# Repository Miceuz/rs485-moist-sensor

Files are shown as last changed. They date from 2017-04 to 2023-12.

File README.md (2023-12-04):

# rs485 soil moisture sensor
Digital (RS485 - based) soil moisture and temperature sensor 



A version of [I2C soil moisture sensor](https://github.com/Miceuz/i2c-moisture-sensor) with several updates - antistatic protection, local voltage regulation and RS485 networking.

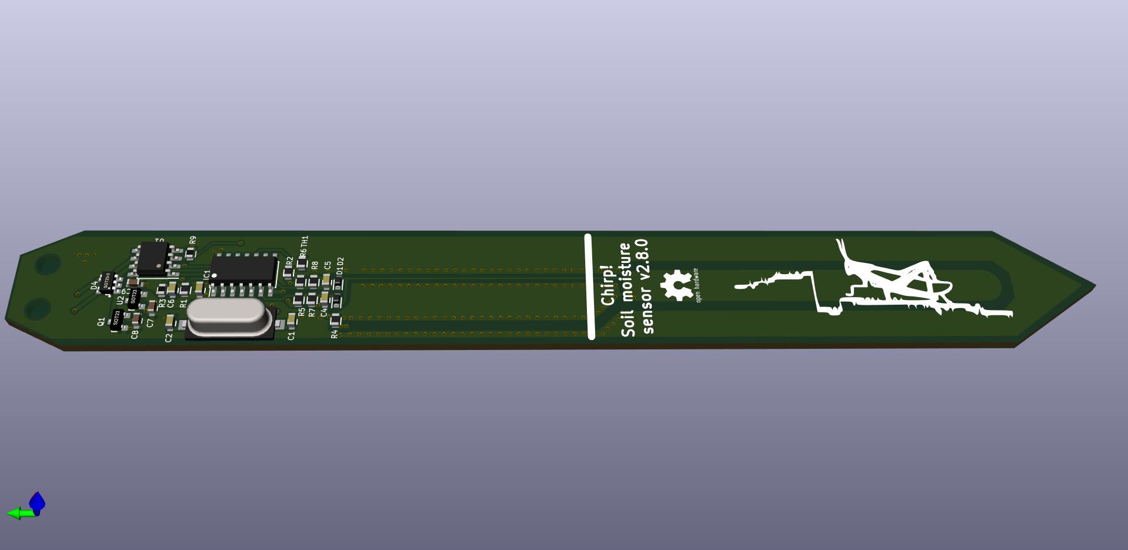
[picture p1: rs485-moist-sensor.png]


This is a contact-less capacitive soil moisture sensor, a continuation of my [I2C soil moisture sensor](https://github.com/Miceuz/i2c-moisture-sensor). This particular version of the sensor is suited for more professional installations where long cable runs is a requirement. It adds a local voltage regulator to mitigate the voltage drop and RS485 transceiver to accommodate long wires, also reverse polarity and an additional ESD protection level is added. 

This is the easiest and the most robust way to read soil moisture and temperature values into Raspberry Pi. I have written a [tutorial](https://github.com/Miceuz/rs485-moist-sensor/tree/master/tutorial) how to do it.

The main features:

 * Capacitive soil moisture sensing
 * Temperature sensing
 * Good stability with temperature
 * Good stability with power variation
 * Suitable for long cable runs
 * Uses industrial Modbus protocol

# Python library

A python library is available via pip. Type `pip install chirp_modbus` to install it. Check the [source code](https://github.com/Miceuz/rs485-moist-sensor/blob/master/utils/lib/chirp_modbus.py) for documentation. Usage example:
```python
from chirp_modbus import SoilMoistureSensor
s = SoilMoistureSensor(1, '/dev/ttyUSB5')
print(s.getTemperature())
print(s.getMoisture())
```

# Technical data

 * Supply voltage - 5V
 * Bus can be run on both 3V and 5V
 * Default serial settings: 19200, 8-bit frame, no parity, 2 stop bits
 * Default Modbus address: 1
 * Current consumption: Active: 9mA, Deep sleep: 11uA

## Principle of operation

Sensor makes periodic measurements (by default, once every 500ms), delays between measurements can be updated by writing to one of the Modbus registers. The results of the measurements are kept in specific Modbus registers and can be read by master any time unless the sensor is in deep sleep. 

Deep sleep is entered by writing a number of seconds to sleep into a special sleep register. The sensor will put the transceiver and all the periphery into the lowest possible power consumption mode and sleep for the specified amoutn of time. After the sleep the sensor will wake up, start taking measurements and be available on the bus till the next sleep command.

Serial communication parameters as baud rate, parity and address can be updated by writing to related registers. The sensor will reset and boot with the new parameters if any of those registers are written.

### Input (read only) registers

|Register number | Size (bytes) | Description |
|---|--- |---|
| 0 | 2 | Soil moisture. Unsigned |
| 1 | 2 | Temperature. Signed. In tenths of degrees Celsius. I.e. 220 means 22.0C |

### Holding (read/write) registers

|Register number | Size (bytes) | Valid values | Default value | Description |
|---|---|--- |---|---|
| 0 | 2 |  [1 - 247] | 1 | Modbus address |
| 1 | 2 |  [0 - 7] | 4 | Baud rate |
| 2 | 2 |  [0 - 2] | 0 | Parity **Note: most cheap ebay USB to RS485 dongles don't support parity properly!** |
| 3 | 2 |  [1 - 65535] | 500 | Measurement interval in milliseconds |
| 4 | 2 |  [1 - 65535] | 0 | Time to sleep in seconds. Write to this register to put the sensor to sleep. |

#### Supported baudrates

 Number | Baudrate
--------|---------
   0    |  1200
   1    |  2400
   2    |  4800
   3    |  9600
   4    |  19200
   5    |  38400
   6    |  57600
   7    |  115200

#### Supported parity settings

 Number | Parity
--------|---------
   0    |  None
   1    |  Even
   2    |  Odd

**Note: most of the cheap ebay USB to RS485 dongles and/or their drivers do not support parity setting properly! You will have to use a proper parity supporting adapter to unbrick the sensor if you set this to something that your dongle does not support!** Luckily Adruino with ATmega 16u2 can be used as USB to Serial adapter to solve this.

## How to interpret the readings

Moisture values are relative. Meaning, more moisture will give you higher reading, less moisture - lower reading. It's up to you to calibrate it to amount of water in the soil as readings will be different for different types of soils. 

Moisture is somewhat linear. I test all sensors before shipping and they give about 292 in free air. 

Temperature is measured by the thermistor on the body of the sensor. Calculated absolute measurement accuracy is better than 2%. The returned value is in tenths of degrees Celsius. I.e. value 252 would mean 25.2°C.

## Controller support

The sensor will work fine with any controller supporting serial communication provided you have an RS485 transceiver. There are a lot of Modbus libraries readily available for a variety of micro-processor families. Thea easiest way to try the sensor is to use one of the abundant and cheap USB to RS485 dongles and connect it to a Raspberry pi or even directly to your computer. 

I have written some basic test code in python that is available on [github](https://github.com/Miceuz/i2c-moisture-sensor/blob/master/README.md) page. 

## Waterproofing

The sensor comes coated with PRF202 - a moisture resistant varnish for electronics. It's ok for play around in a flower pot but not enough for outdoor use. **You must add an additional protection to the whole sensor after soldering cable to it!** Some suggestions on making the sensor more robust after attaching the cable:

 * Polyester or epoxy resin - this method is the most bullet proof as the resin is totally resistant to the water. On the par side, note that sensitivity of the sensor will decrease depending on how thick the layer you are going to apply. Also applying the resin in uniform manner presents some challenge.
 * PlastiDip - some of my customers have tried this method - easy to apply by spraying and not a lot of loss of sensitivity.
 * Rubber balloon - yes, just roll a long balloon over the sensor :)  

Be sure to coat the whole thing - the sensor part, the electronics and the cable connection itself so no bare copper or solder is accessible to the water.

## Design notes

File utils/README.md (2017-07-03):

# Python utils for RS485 soil moisture sensor

These utils demonstrate how to read and write registers to the sensor via Modbus. Utils use a  [minimalmodbus library](https://minimalmodbus.readthedocs.io/en/master/) refer to their documentation for installation instructions and more info.

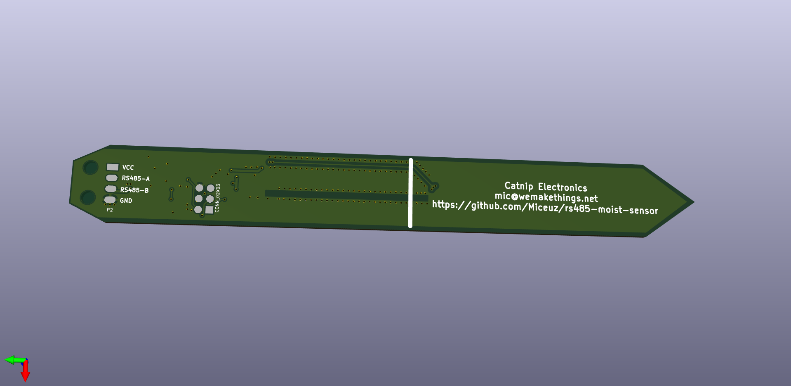
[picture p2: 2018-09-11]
rs485-moist-sensor-back.png

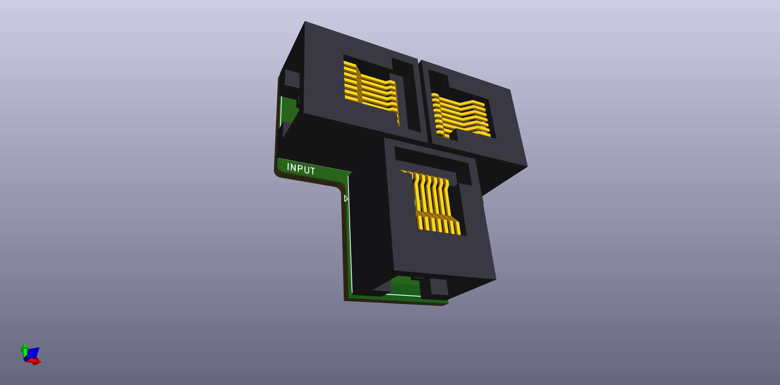
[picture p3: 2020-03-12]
interconnect/interconnect.png

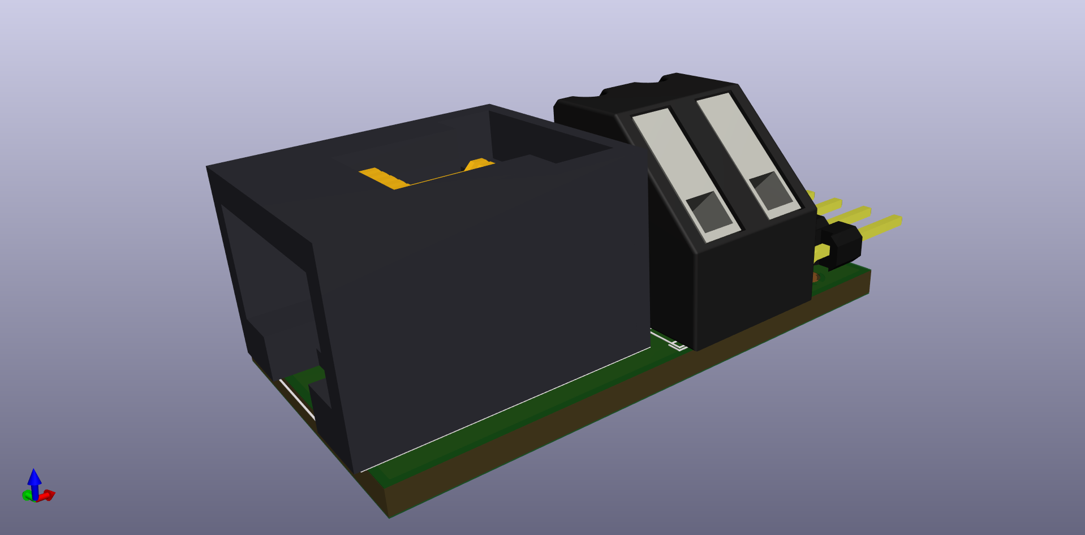
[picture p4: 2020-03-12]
adapter-por/adapter-por.png

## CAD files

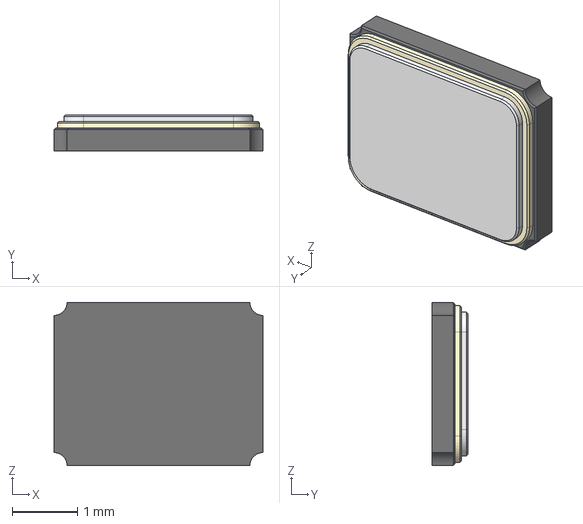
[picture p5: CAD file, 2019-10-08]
3d/CRY_SMD3225.STEP
3.20 x 0.55 x 2.50 mm

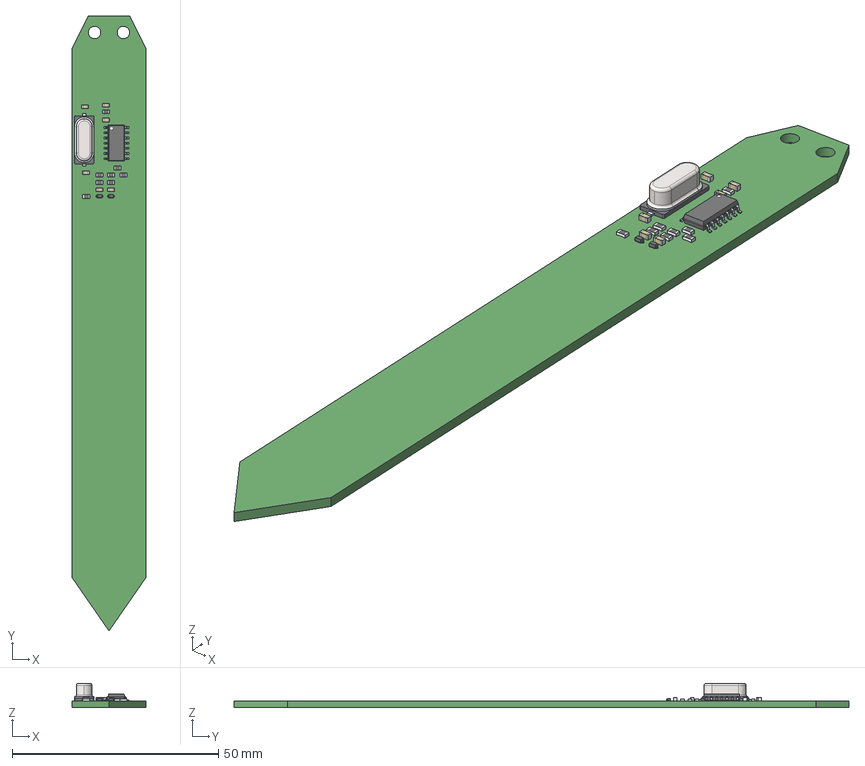
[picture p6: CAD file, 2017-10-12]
rs485-moist-sensor.stp
18.0 x 149.0 x 5.90 mm

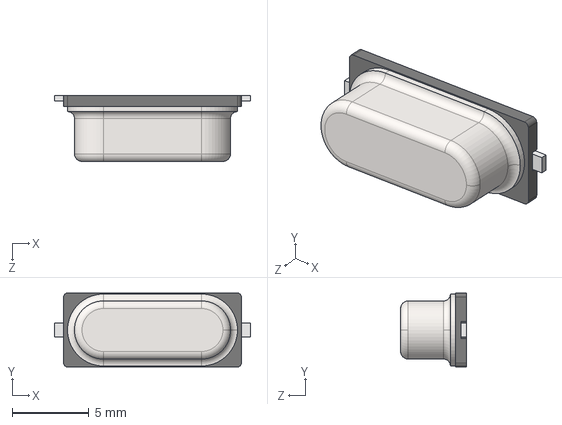
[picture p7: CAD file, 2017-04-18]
3d/User Library-Crystal HC49_US-SM.STEP
12.8 x 4.83 x 4.30 mm

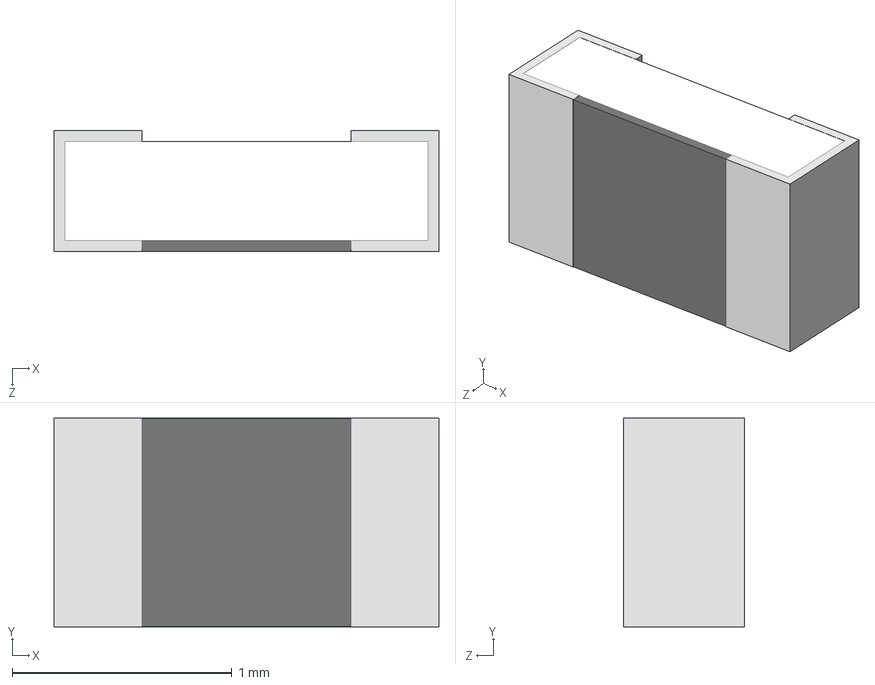
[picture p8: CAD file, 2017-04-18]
3d/User Library-RES_SMD-1.STEP
1.75 x 0.95 x 0.55 mm

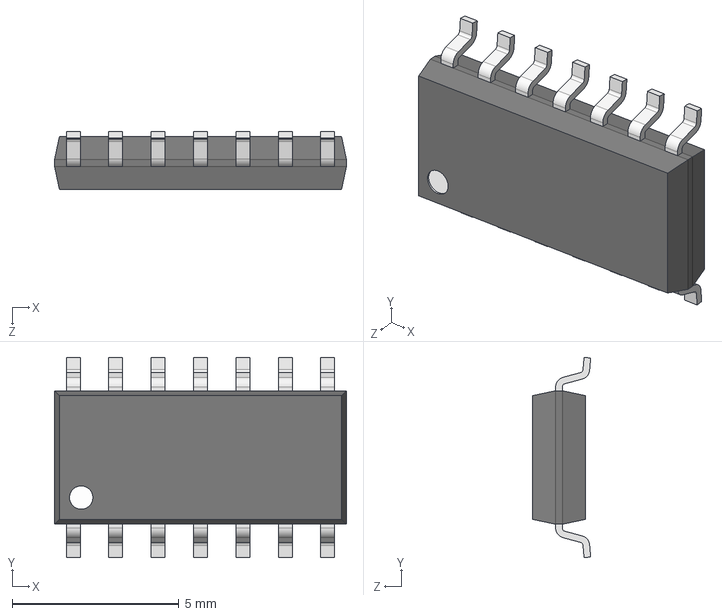
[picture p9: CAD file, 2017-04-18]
3d/User Library-SOIC-14.STEP
8.75 x 6.00 x 1.75 mm

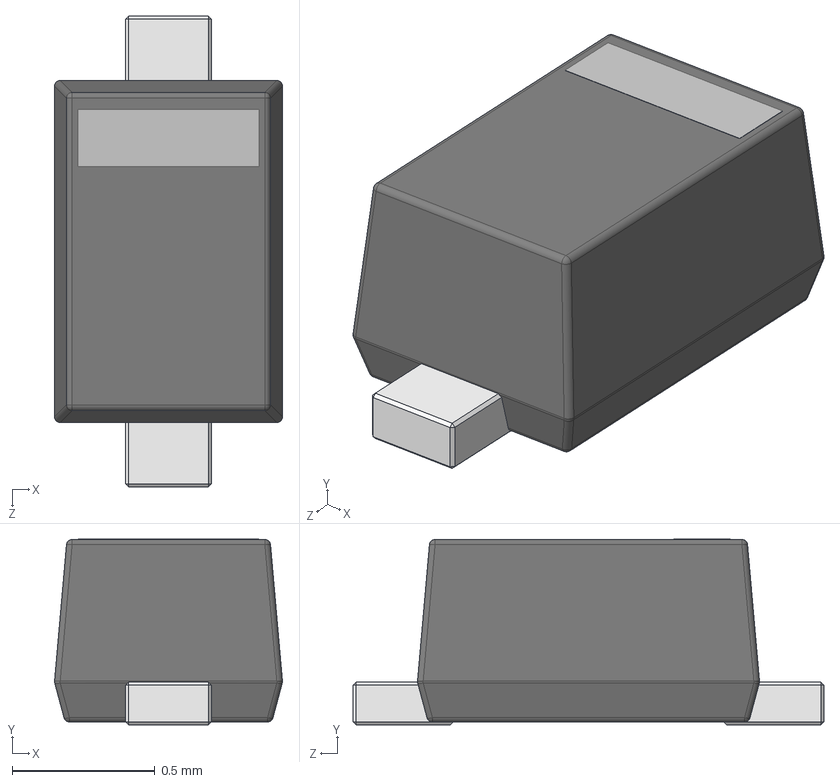
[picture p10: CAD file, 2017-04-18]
3d/User Library-SOD523-2.STEP
0.8 x 0.651 x 1.65 mm

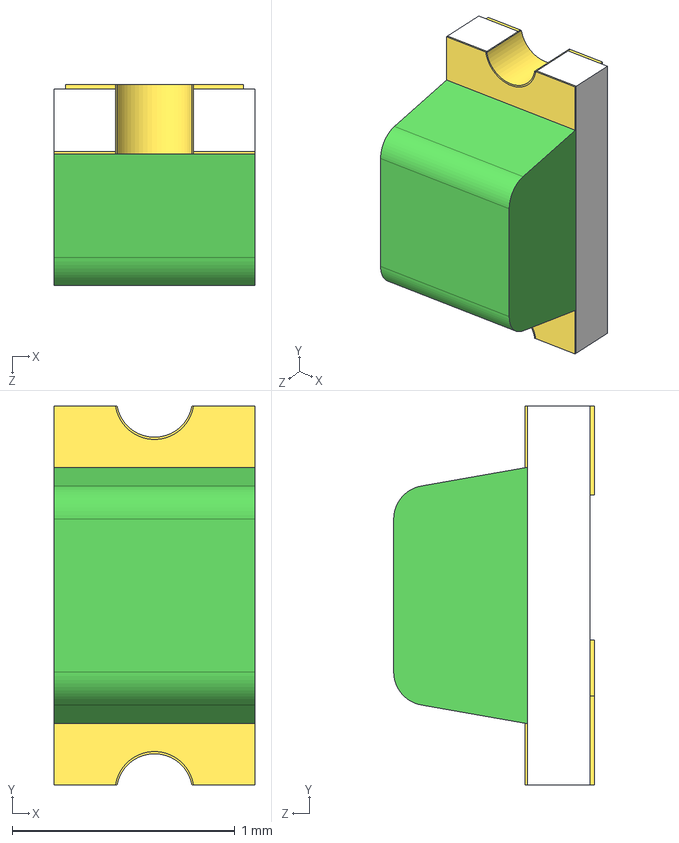
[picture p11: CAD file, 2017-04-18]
3d/User Library-LTST-C190GKT.STEP
0.9 x 1.70 x 0.9 mm
User Library-LTST-C190GKT_Pad005
User Library-LTST-C190GKT_Pad001
User Library-LTST-C190GKT_Pad004
User Library-LTST-C190GKT_Pad003
User Library-LTST-C190GKT_Lens
User Library-LTST-C190GKT_Pad

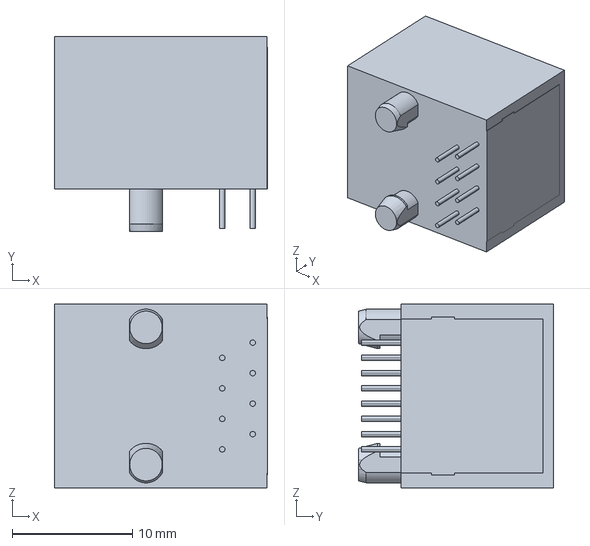
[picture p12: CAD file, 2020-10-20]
interconnect/54602-908LFc.stp
17.7 x 16.2 x 15.3 mm

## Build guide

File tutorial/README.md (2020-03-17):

# Talking to RS485 soil moisture sensor from Raspberry Pi

This tutorial will guide you how to get soil moisture and temperature readings from Chirp RS485 soil moisture sensor. These instructions are written with RaspberryPi in mind, but actually are valid for every python installation on Windows, Linux or OSX.

## What is RS485? Modbus?

RS485 is a standard defining the electrical characteristics for use in serial communications systems. It is a vary robust protocol allowing multiple devices on the same wire and long cable runs. Cable with at least 4 conductors is used to connect the sensors. You can hook up over 200 sensors on the same bus.

Modbus is a proven, industry standard protocol that goes over RS485 signalling layer. Communication happens between one master and multiple slaves. Each slave has to have a unique address. Master can read and write configuration and data registers of slave. Framing and data integrity is taken care of.

### USB - to - RS485 dongles

To talk to the sensor you will need a dongle that allows you computer to talk and listen on the RS485 network. Luckily RS485 is so popular that there is multitude of cheap dongles to choose from on ebay. Just enter "USB RS485" into the search terms and you will get a lot to choose from. Below are some examples that work fine. For convenience, choose one that has power pins +5V and GND broken out on the connector. Also you can hack the dongle by soldering wires to such points on the board.

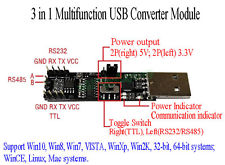
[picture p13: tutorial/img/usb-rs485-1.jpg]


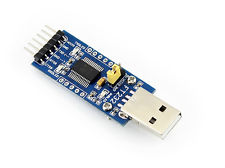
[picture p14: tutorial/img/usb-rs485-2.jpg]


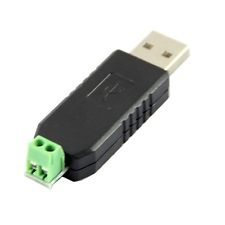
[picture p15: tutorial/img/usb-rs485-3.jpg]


### Wiring the connections

The sensor has 4 connections:

 * VCC - positive power supply. Apply 5V to this pin.
 * RS485-A - noninverting line of RS485 bus
 * RS485-B - inverting line of RS485
 * GND - negative power supply  

## Installing required software

Python environment and a chirp_modbus library is needed to communicate with the sensor.

To install all the needed Python infrastructure, type: 

```
sudo apt-get install python-pip
```

To install the chirp_modbus Python library type:

```
sudo pip install chirp_modbus
```

BAM! You are ready to go!

## Connecting to RS485 network

USB to RS485 dongle is really a simple device - it is just a simple USB to serial adapter plus a special RS485 transceiver chip. This means, that when you insert the dongle into your computer, a serial port will be created by your operating system. In Linux and OS X this happens automagically, but in Windows you will need to download the driver for the particular UST to serial chip used in your dongle. My example dongle uses CP2102.

Enter this command before inserting the dongle into Raspberry Pi: 
```
tail -f /var/log/syslog
```

Then insert the dongle. Something like this will appear:

```
Aug 30 20:37:01 raspberrypi kernel: [  839.161890] usb 1-1.2: new full-speed USB device number 4 using dwc_otg
Aug 30 20:37:01 raspberrypi kernel: [  839.297949] usb 1-1.2: New USB device found, idVendor=10c4, idProduct=ea60
Aug 30 20:37:01 raspberrypi kernel: [  839.297973] usb 1-1.2: New USB device strings: Mfr=1, Product=2, SerialNumber=3
Aug 30 20:37:01 raspberrypi kernel: [  839.297985] usb 1-1.2: Product: CP2102 USB to UART Bridge Controller
Aug 30 20:37:01 raspberrypi kernel: [  839.297995] usb 1-1.2: Manufacturer: Silicon Labs
Aug 30 20:37:01 raspberrypi kernel: [  839.298005] usb 1-1.2: SerialNumber: 0001
Aug 30 20:37:01 raspberrypi mtp-probe: checking bus 1, device 4: "/sys/devices/platform/soc/20980000.usb/usb1/1-1/1-1.2"
Aug 30 20:37:01 raspberrypi mtp-probe: bus: 1, device: 4 was not an MTP device
Aug 30 20:37:01 raspberrypi kernel: [  839.474676] usbcore: registered new interface driver usbserial
Aug 30 20:37:01 raspberrypi kernel: [  839.474812] usbcore: registered new interface driver usbserial_generic
Aug 30 20:37:01 raspberrypi kernel: [  839.474941] usbserial: USB Serial support registered for generic
Aug 30 20:37:01 raspberrypi kernel: [  839.489032] usbcore: registered new interface driver cp210x
Aug 30 20:37:01 raspberrypi kernel: [  839.489190] usbserial: USB Serial support registered for cp210x
Aug 30 20:37:01 raspberrypi kernel: [  839.489396] cp210x 1-1.2:1.0: cp210x converter detected
Aug 30 20:37:01 raspberrypi kernel: [  839.523446] usb 1-1.2: cp210x converter now attached to ttyUSB0
Aug 30 20:38:50 raspberrypi systemd[1]: Starting Cleanup of Temporary Directories...
Aug 30 20:38:51 raspberrypi systemd[1]: Started Cleanup of Temporary Directories.
```

This line is of importance here:

```
Aug 30 20:37:01 raspberrypi kernel: [  839.523446] usb 1-1.2: cp210x converter now attached to ttyUSB0
```

This means, the dongle now is accessible via /dev/ttyUSB0 serial port. Now it's time to write some code.

## Connecting to the sensor

From the command line start the Python interpreter:

```
$ python
```

You will be welcomed by Python interpreter:

```
$ python
Python 2.7.13 (default, Jan 19 2017, 14:48:08) 
[GCC 6.3.0 20170124] on linux2
Type "help", "copyright", "credits" or "license" for more information.
>>>
```

Type these commands:

```python
>>> import chirp_modbus
>>> sensor = chirp_modbus.SoilMoistureSensor(address=1, serialport='/dev/ttyUSB0')
>>> sensor.getMoisture()
201
```

BAM! You have just read moisture from the sensor! Try reading from the different register:

```python
>>> sensor.getTemperature()
20.0
```

Read the [source code](https://github.com/Miceuz/rs485-moist-sensor/blob/master/utils/lib/chirp_modbus.py) of the library for more.

## Addressing the sensors
All the sensors come with the same address preprogrammed to them, it's address **1**. Before using several sensors on the same bus, you have to assign unique address to each sensor. Luckily, this is just a matter of writing the address to the special Holding register:
```python
>>>sensor.setAddress(42)
```
This will set the address of the sensor to **42**. Sensor will reset and will listen on the new address immediately.

## Useful utilities
```python
#!/usr/bin/python

"""Waits for the sensor to appear on /dev/ttyUSB0, then reads moisture and temperature from it continuously"""

import chirp_modbus
from time import sleep

ADDRESS = 1

while True:
	try:
		sensor = chirp_modbus.SoilMoistureSensor(address=ADDRESS, serialport='/dev/ttyUSB0')
		# sensor.sensor.debug=True
		print(" Moisture=" + str(sensor.getMoisture()) +
			  " Temperature=" + str(sensor.getTemperature()))
		sleep(0.1)
	except (IOError, ValueError):
		print("Waiting...")
		sleep(0.3)
```

Address manipulation example:

```python
#!/usr/bin/python

"""Looks for sensor with ADDRESS1 and changes it's address to ADDRESS2 then changes it back to ADDRESS1""" 

import chirp_modbus
from time import sleep
ADDRESS1 = 1
ADDRESS2 = 2

sensor = chirp_modbus.SoilMoistureSensor(address=ADDRESS1, serialport='/dev/ttyUSB0')

print("writing new address: " + str(ADDRESS2))
sensor.setAddress(ADDRESS2)

sleep(0.2)
print("reading address from holding register: ")
print(sensor.getAddress())

print("writing new address: " + str(ADDRESS1))
sensor.setAddress(ADDRESS1)

sleep(0.2)

print("reading address from holding register: ")
print(sensor.getAddress())
```

Bus discovery example:
```python
import chirp_modbus

found = chirp_modbus.SoilMoistureSensor.scanBus(serialport='/dev/ttyUSB0', verbose=True, findOne=True, startAddress = 1, endAddress = 247)
```

### Bonus - pushing data to the Thingspeak

If you want to push your data to Thingspeak cloud, here is what you have to do.

Download thingspeak Python library:

```
$sudo pip install thingspeak
```
Set up your streak in [thingspeak.com](https://thingspeak.com)
Use this utility:

```python
#!/usr/bin/python
import chirp_modbus
from time import sleep, time
import thingspeak

channel = thingspeak.Channel(302723, api_key='YOUR API KEY', write_key='YOUR WRITE KEY')

SENSOR_PORT = '/dev/ttyUSB0'
ADDRESS = 1

sensor = chirp_modbus.SoilMoistureSensor(address=ADDRESS, serialport=SENSOR_PORT)

lastPostTimestamp = time()

moisture = 0
temperature = 0

while True:
	if time() - lastPostTimestamp > 3:
		try:
			moisture = sensor.getMoisture()
			temperature = sensor.getTemperature()
			try:
				channel.update({'field1':moisture, 'field2':temperature})
			except:
				print("#could not post")
			print(moisture, temperature)
		except(IOError, ValueError):
			print("#could not read sensor")
		
		lastPostTimestamp = time()

```

That's it folks! Please provide me feedback and send me pull requests!

### Bonus2 - pushing data to the local InfluxDB instance

```python
#!/usr/bin/python
import minimalmodbus
import serial
from time import sleep, time
from influxdb import InfluxDBClient
import RPi.GPIO as gpio

READING_INTERVAL_S = 3
SENSOR_PORT = '/dev/ttyUSB0'

ADDRESS = 1
minimalmodbus.CLOSE_PORT_AFTER_EACH_CALL = True
minimalmodbus.PARITY=serial.PARITY_NONE
minimalmodbus.STOPBITS = 2
minimalmodbus.BAUDRATE=19200
sensor = minimalmodbus.Instrument(SENSOR_PORT, slaveaddress=ADDRESS)

gpio.setmode(gpio.BCM)
gpio.setup(27, gpio.OUT)

lastPostTimestamp = time()

moisture = 0
temperature = 0

dbclient = InfluxDBClient(host='localhost', port=8086)
dbclient.switch_database('soil_sensors')

def formatForDb(moisture, temperature):
	points=[{
			"measurement":"data", 
            "tags":{"plant":"begonija"}, 
			"fields":{"temperature":temperature*1.0, "moisture":moisture*1.0}
			}]
	return points

def formatForDb(moisture, temperature, sensor_status):
	points=[{
			"measurement":"data", 
            "tags":{"plant":"begonija"}, 
			"fields":{"temperature":temperature*1.0, 
					  "moisture":moisture*1.0, 
					  "sensor_status":sensor_status}
			}]
	return points

def formatForDb(sensor_status):
	points=[{
			"measurement":"data", 
            "tags":{"plant":"begonija"}, 
			"fields":{"sensor_status":sensor_status}
			}]
	return points

def postToDb(points):
	try:
		dbclient.write_points(points)
		gpio.output(27, gpio.HIGH)
	except:
		print("#could not post")
		gpio.output(27, gpio.LOW)

try:
	while True:
		if time() - lastPostTimestamp > READING_INTERVAL_S:
			try:
				moisture = sensor.read_register(0, functioncode=4)
				temperature = sensor.read_register(1, functioncode=4, numberOfDecimals=1, signed=True)
				postToDb(formatForDb(moisture, temperature, "OK"))
			except(IOError, ValueError):
				postToDb(formatForDb("ERROR"))
				gpio.output(27, gpio.LOW)
				print("#could not read sensor")

			lastPostTimestamp = time()
except KeyboardInterrupt:
	print("Exiting...")
finally:
	GPIO.cleanup()

```

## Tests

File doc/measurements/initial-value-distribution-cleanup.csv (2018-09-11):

##Begins...
213 | 193
213 | 194
213 | 194
213 | 194
213 | 194
211 | 177
211 | 177
211 | 178
211 | 178
211 | 179
209 | 192
209 | 192
209 | 192
210 | 193
210 | 175
210 | 175
210 | 175
210 | 176
211 | 172
211 | 172
211 | 172
211 | 173
211 | 173
211 | 174
211 | 174
211 | 180
211 | 180
211 | 180
210 | 181
210 | 181
211 | 181
#Error: 226
210 | 183
210 | 183
210 | 183
210 | 183
210 | 183
210 | 185
210 | 185
211 | 174
211 | 174
211 | 174
211 | 174
210 | 175
210 | 175
210 | 175
212 | 178
212 | 179
212 | 179
211 | 180
212 | 176
212 | 176
212 | 176
212 | 177
212 | 177
212 | 178
212 | 178
212 | 178
211 | 173
211 | 173
211 | 174
211 | 174
211 | 175
211 | 175
210 | 176
210 | 178
210 | 178
210 | 179
210 | 179
210 | 179
210 | 179
210 | 179
210 | 181
210 | 181
210 | 181
#Error: 226
#Error: 226
210 | 189
210 | 190
210 | 190
210 | 191
210 | 191
210 | 191
209 | 191
209 | 191
210 | 191
210 | 174
209 | 174
209 | 174
210 | 174
210 | 174
210 | 174
209 | 175
#Error: 226
209 | 176
208 | 177
208 | 177
207 | 178
207 | 178
208 | 179
208 | 179
208 | 179
208 | 179
209 | 177
209 | 177
209 | 178
209 | 178
209 | 178
209 | 179
209 | 179
#Error: 226
#Error: 226
#Error: 226
209 | 183
209 | 183
209 | 183
208 | 183
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

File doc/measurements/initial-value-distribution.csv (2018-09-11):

##Begins...
213 | 193
213 | 194
213 | 194
213 | 194
213 | 194
211 | 177
211 | 177
211 | 178
211 | 178
211 | 179
209 | 192
209 | 192
209 | 192
210 | 193
210 | 175
210 | 175
210 | 175
210 | 176
211 | 172
211 | 172
211 | 172
211 | 173
211 | 173
211 | 174
211 | 174
211 | 180
211 | 180
211 | 180
210 | 181
210 | 181
211 | 181
#Error: 226
360 | 180
210 | 183
210 | 183
210 | 183
210 | 183
210 | 183
210 | 185
210 | 185
211 | 174
211 | 174
211 | 174
211 | 174
210 | 175
210 | 175
210 | 175
212 | 178
212 | 179
212 | 179
211 | 180
212 | 176
212 | 176
212 | 176
212 | 177
212 | 177
212 | 178
212 | 178
212 | 178
211 | 173
211 | 173
211 | 174
211 | 174
211 | 175
211 | 175
210 | 176
210 | 178
210 | 178
210 | 179
210 | 179
210 | 179
210 | 179
210 | 179
210 | 181
210 | 181
210 | 181
#Error: 226
#Error: 226
210 | 189
210 | 190
210 | 190
210 | 191
210 | 191
210 | 191
209 | 191
209 | 191
210 | 191
210 | 174
209 | 174
209 | 174
210 | 174
210 | 174
210 | 174
209 | 175
#Error: 226
209 | 176
208 | 177
208 | 177
207 | 178
207 | 178
208 | 179
208 | 179
208 | 179
208 | 179
209 | 177
209 | 177
209 | 178
209 | 178
209 | 178
209 | 179
209 | 179
#Error: 226
#Error: 226
#Error: 226
209 | 183
209 | 183
209 | 183
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

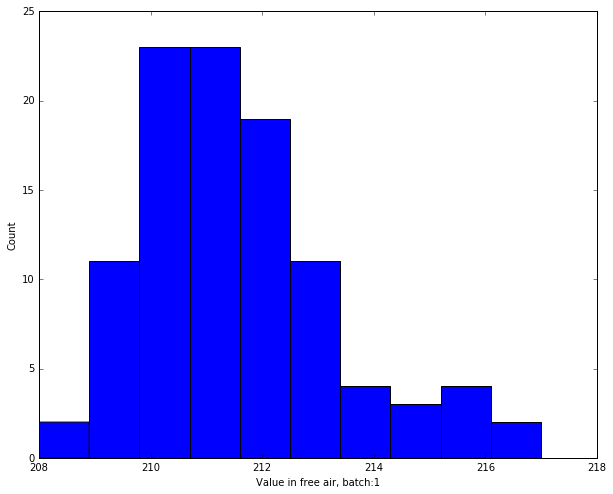
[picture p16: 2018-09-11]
doc/measurements/initial-value-batch1.png

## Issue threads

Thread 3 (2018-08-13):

measurement interval lost after sensor reboot

impellerturn, 2018-08-13:
Hi,
i somehow have an issue with the measurement interval.
it seems that its  not correctly stored in EEPRom and initialized to a very high value after power off->on.

here is what i did:
>>> pi@raspberrypi:~/Documents/WateringSystem $ python3
>>> Python 3.5.3 (default, Jan 19 2017, 14:11:04)
>>> [GCC 6.3.0 20170124] on linux
>>> Type "help", "copyright", "credits" or "license" for more information.
>>> from chirp_modbus import SoilMoistureSensor
>>> sensor = SoilMoistureSensor(10, "/dev/ttyUSB0")
>>> sensor.getMeasurementInterval()
65524
>>> sensor.setMeasurementInterval(123)
>>> sensor.getMeasurementInterval()
123

**Power off sensor, power back on**

>>> sensor.getMeasurementInterval()
65524

**Reinitialize python object, turns out this was not the issue**

>>> sensor = SoilMoistureSensor(10, "/dev/ttyUSB0")
>>> sensor.getMeasurementInterval()
65403
>>> sensor.getMeasurementInterval()
65403
>>> sensor.getMeasurementInterval()
65403
>>> sensor.getMeasurementInterval()
65403
**set another interval**
>>> sensor.setMeasurementInterval(123)
>>> sensor.getMeasurementInterval()
123
>>> sensor.getMeasurementInterval()
123
>>> sensor.getMeasurementInterval()
123
>>> sensor.getMeasurementInterval()
123
>>> sensor.getMeasurementInterval()
123
>>> sensor.getMeasurementInterval()
123
>>> sensor.getTemperature()
26.4
>>> sensor.getTemperature()
26.4
>>> sensor.getTemperature()
26.4
>>> sensor.getMoisture()
229

** here the test, if the data is updated fast, yes it is**
>>> sensor.getMoisture()
416
>>> sensor.getMoisture()
227
>>> sensor.getMoisture()
227
>>> sensor.getMeasurementInterval()
123
>>> sensor.setMeasurementInterval(500)
>>> sensor.getMeasurementInterval()
500
>>> sensor.getMeasurementInterval()
500
>>> sensor.getMeasurementInterval()
500
>>> sensor.getMeasurementInterval()
500

** power off sensor, power back on**

>>> sensor.getMeasurementInterval()
65524
>>> sensor.getMeasurementInterval()
65524

cheeeeee, 2019-02-10:
I realize this is old but you are correct. There was an error with how the measurement interval was stored to eeprom.  I THINK I have this fixed but i'm still going through stuff and I'm not sure this project is even supported any more.

Miceuz, 2019-02-11:
Hi, the project is still very much supported, thanks for your contributions. Would you mind forking it from mine and adding you changes to the forked branch so I could import them to my repository?

Thank you very much for the contribution! I am a bit busy right now, but I will come back to your questions in couple days.

cheeeeee, 2019-02-11:
Oh yeah it's already forked and under [https://github.com/cheeeeee/RS485_AtmelDebug/tree/master/src](https://github.com/cheeeeee/RS485_AtmelDebug/tree/master/src). The issue here was a mismatch between the initial array declaration being u16 and the eeprom stores being u8.  On my branch everything is u16 and all values are written to eeprom as u16 and loaded as u16.  Also the loadconfig() function wasn't fully finished and now is in working order.  I'm still working on stuff so I don't know if I really have a stable build yet or not so you have time.

impellerturn, 2019-02-12:
Hi,
good to hear from you.
I have 3 of these sensors and are also still interested in bugfixes.
Best regards

cheeeeee, 2019-02-17:
Added some possibly stable .elf and .hex files at [https://github.com/cheeeeee/RS485_AtmelDebug/tree/master/src/Release](https://github.com/cheeeeee/RS485_AtmelDebug/tree/master/src/Release)
If anyone is brave enough to try and flash their sensors.  Hopefully I can get a programming setup to test these patches out this week.

impellerturn, 2019-02-24:
Hi,
mine are buried and also sealed, so "quick testing" is not possible for me :(
Sorry, best regards

Miceuz, 2019-03-03:
I think this bug might be a combination of the bug in the library as incorrect register number was specified for measurement interval AND MAYBE eeprom saving issue. @cheeeeee is correct - I should be saving 16bit values, not 8 bit. Even though I don't use them all. Will work on that

cheeeeee, 2019-03-18:
Yeah when I was going through it you could do a mix of 8 bit and 16 bit ints but honestly it's just way easier to make everything 16 bit even if it's a little inefficient.  If there's anything you want me to look at more in depth just let me know i'll be happy to do it.

Gagi2k, 2020-04-20:
I guess my sensors have the same bug. I have 20 sealed sensors, most of them buried, but i also have some replacements at my desk. Do you think these saving issues can also affect other areas (not just the measurement interval) which could make the device stop working completely and not answer anymore ?
All my replacement sensors (which were not used once, just used for a basic check when i got them) are all not answering anymore. I extended your python library to scan all baudrate/parity combinations, but no response. Any help on what i can do to debug the problem or fix/reflash is very welcome *g*

impellerturn, 2020-04-21:
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

I had a similar issue with the sensors stopping reponding. But i did not associate it with the storing problem.
I was reading the values for temp and moisture every second and after a while (random, usually something between 2 and 24 hours) none of the sensors attached to the bus was reponding.
Only thing that helped was cutting the power supply and giving them a hard-restart.
At that point i´ve discarded the idea of measuring moisture and went back to basic time sheduling of my irrigation system.

chris-b-tanner, 2021-04-18:
Is this issue still open? I have similar behaviour across multiple sensors; after powering down and up again the reading interval requires checking and resetting regularly to ensure correct readings. I also have the odd occurrence when the slave ID is reset to 1, which causes much more trouble as when there are multiple devices on the bus, it's not fixable by the master.

Miceuz, 2021-04-19:
I have pinpointed that to a power sequencing issue. I don't know yet what, but something causes the sensor to corrupt eeprom when power is rising/falling too slow. I.e. this should happen while turning of/on the whole string of sensors.

Increasing BOD value seemed to help, so I did that for my current batch of sensors.

But also I have a hardware solution that powers sensors and disconnects both power and modbus lines when voltage is too low. If anyone wants, I can send that as a bandaid fix for this problem, contact me directly plz.

Also just disconnecting cable instead of allowing slow switch off of the power supply is an option if you have it on a connector.

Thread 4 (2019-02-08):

A few questions about the ATTiny441 programming

cheeeeee, 2019-02-08:
If you get a chance I had a few questions about some of the modbus programming in modbus.c and main.c
# Possible problems:
### In modbus.c --

#### Function Problems:
`bool validateFrame()`
Line 169 -- `uint8_t requestedAdr = getRequestedAddress();`  `requestedAdr` is never used in this function.
`ISR(UART_RECEIVE_INTERRUPT)`
Line 210 -- `uint8_t parityError = (UCSR0C & _BV(UPM01) && (UCSR0A & _BV(UPE0)));`never used in this function.

### In main.c --
#### General Problems:

`F_CPU`
This is defined by default in delay.h as 1MHz and defines the clock cycle. This is probably undefined behavior.

Line 193 -- `ISR(WDT_vect)`
WDT_vect isn't supported on the ATTiny44 according to [https://www.nongnu.org/avr-libc/user-manual/group__avr__interrupts.html](https://www.nongnu.org/avr-libc/user-manual/group__avr__interrupts.html). This is supported if you use Atmel's special header file iotn441.h
This might explain the comment saying you were having problems with it.

#### Function Problems:
`modbusGet(void)`
Line 123 -- `if (modbusIsFrameAvailable())` when true this enters a switch case statement with a default behavior, however there is no error returned if `modbusIsFrameAvailable()` returns false.
Between line 160 and 161 a modbus error should probably be returned to handle a false boolean.

`sleep()`
Line 234 -- might not be a problem but I think you have an unneeded compare.
on line 228 you have `secondsToSleep = holdingRegisters.asStruct.sleepTimes;`
since you've assigned these values to be equal when you do the compare on line 235 `while((sleepTimes > 0) || (secondsToSleep > 0))` I'm pretty sure you're just checking two numbers that are always the same in this particular function.  You can probably use if and just check one.

Line 297 -- incorrect primitive for main
```
void main (void) {
}
```
should be
```
int main (void) {
}
```

Lines 318 and 324

Incorrect primitives for temp.  Needs to be signed to allowed for negative values. Initial declaration is correct but is incorrect in function call.

`(uint16_t*) &(inputRegisters.asStruct.temperature));`
should be
`(int16_t*) &(inputRegisters.asStruct.temperature));`

# Questions!
1. What do you think the F_CPU cycle should be set to? I'm assuming 16MHz to match the crystal but it might be 8 MHz to match the ATTiny441 default clock.
2.  Currently if I write to a value to the sleep register it won't wake up until that counter expires or the sensor is power cycled.  Is this intentional or a bug? It seems like requesting a read operation should wake the sensor.  I think with the  iotn441.h header fix this could be easily done with a watchdog interrupt.

You can find everything I've done to these files at [https://github.com/cheeeeee/RS485_AtmelDebug](https://github.com/cheeeeee/RS485_AtmelDebug) Including some additional API documentation in main.c if you haven't looked at this in a while and need a refresher.

cheeeeee, 2019-02-15:
I answered question 1 for myself.  Turns out iT was defined in the original makefile as 16MHz and my compiler was giving me an undefined error because Atmel studio was managing my makefile for me.

Miceuz, 2019-03-03:
Hi, thanks for your feedback.

F_CPU is defined in Makefile

This is attiny441, not attiny44, avr-libc was lagging behind a bit.

modbusGet is polled from the mail loop, it does not result in error if there is no modbus frame to process, it simply did not come yet.

You are right about double nested sleep loop - something is fishy there. But you are mixind two things sleepTimeS means "sleep time in seconds" while sleepTimes means how many times sleep was performed.

Also you are right regarding the pointer type for the temperature -- will fix that.

Tha fact that sensor is not accessible during sleep is by design as I want to save the power by putting the rs485 transceiver to shutdown also. I do that by disabling both reader and driver.

Thanks again for you contribution!

cheeeeee, 2019-03-05:
Yep. I was a little confused since the astruct and variable had the same name. I clarified that in my pull request if you don't mind it.  Thanks for getting back to me.  Hopefully I can flash the firmware on my sensor with my updated code to make sure it's gonna work when I get a chance to.

Closed 2019-03-05.

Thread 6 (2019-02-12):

RS485 Bus stops after a few days

impellerturn, 2019-02-12:
Hello,
i´ve encountered, that my sensors are not working after a few days of operation.
### Setup
- 3 Sensors
- overall bus length 25m
- Termination: VCC <-> 390Ohms <-> RS485-line-A <-> 220Ohms <-> RS485-line-B <-> 390Ohms <-> Ground
- Termination is at my USB to RS485 Transceiver

### Measurement
- set measuerement interval to 500ms
- do 100 measuerements, read the data once per second then calculate mean on the data
- then do the next 100 measuerements

### Result
- This runs fine for about 2 days but occasionally stops.
- Tested with the USBtoRS485 converter sold by @Miceuz and also with a different one. Same results.
- Only pwer cycling the whole bus helps.

Has anyone else had similar issues? Maybe @[cheeeeee](/cheeeeee)?

Any help appreaciated, thanks and best regards

cheeeeee, 2019-02-12:
My initial thought might be the watchdog timer on it. It looks like the WDTCSR is still in the works honestly. I don't even have my sensors in production yet since I'm still going through the firmware.  I'll see about looking into improving the watchdog on it and submitting a pull request since Albertas seems pretty busy.  If you're not familiar, a watchdog timer basically monitors for a loop condition and if a timeout is reached it resets the device automatically.  To keep that from happening you have to keep on feeding the watchdog timeout conditions.  Is there a delay between when you do batches of measurements? Can you try a lower number of reads and report back? Like say 50 reads and average and see if it dies in 2 days or something like 4 days?

impellerturn, 2019-02-14:
Hi,
i´ve tried bringing my system up yesterday but something with MQTT did not work out. Will look for it on the weekend.
Here is my code to use the sensors. It requires the mosquitto python module along with some standard python libs. Dont have a public repo yet.

[soilmoisturereader.zip](https://github.com/Miceuz/rs485-moist-sensor/files/2863887/soilmoisturereader.zip)

Best regards

cheeeeee, 2019-02-14:
Okay just fair warning I haven't used python before but everything that I see on your controllers looks good to me.  Most errors are handled and you should be getting exceptions reported if there is an error in the controller querying the modbus devices.  Try using a lower query rate like I suggested before and see if that changes anything.  If it does that might indicate a limit or bug with MQTT. There was a POSSIBLE error with a write protected register in attint441 programming when sleep was called and a reset might not be initiated and an infinite loop would occur. I included that fix with with other request but I have all of 4 weeks of experience with cpp and about 3 weeks of experience writing c so I'm mostly going off of datasheets and research here.  Albertas will really need to check it all and program one and see what happens.  If what I have doesn't fix it we might have to approach it from a different angle. Just wait and see at this point. Hopefully this works.

Miceuz, 2019-03-03:
@cheeeeee reset() in not called from sleep().

Sensor is configured in Safety Level 1.

> In this mode, the Watchdog Timer is initially disabled, but can be enabled by writing the WDE bit to one without any restriction. A timed sequence is needed when disabling an enabled Watchdog Timer.

@impellerturn are you putting sensors to sleep?

impellerturn, 2019-03-03:
Hi,
no i do not bring the sensors to sleep.

Miceuz, 2021-04-18:
Sorry, I have totally forgotten this.

My suspicion lies with the powering. How many sensors are powered from a single usb dongle? I wouldn't use USB dongle as a permanent power solution. It can supply only one - two sensors.

impellerturn, 2021-04-19:
There were 3 sensors powered by the usb dongle.
In the first post i've listed a detailed description of the system setup.

As of today i do not have the setup any more.

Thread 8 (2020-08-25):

Compiling Toolchain

yuregir, 2020-08-25:
Hello,

I am having some problems with compiling the code.
I am using Mac and brew to setup the toolchain.
I am not able to compile using 4.9.2 compiler which isnt have attiny definitions, the minimum version I can use is 5.3 compiler, when I am using 5.3 compiler code compiles succesfully but, rs485 tranciever enable pin stuck at transmit mode so sensor is not able to receive any modbus data.
There is something I am missing but coulnt find root of the issue
I was wondering anyone can help me on toolchain setup. Or is there any precompiled binary ?

Regards

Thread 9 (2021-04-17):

Sensor readings incorrect when temp below zero

chris-b-tanner, 2021-04-17:
I have a range of sensors based on the schematic and layout of this project, which work brilliantly - apart from when the temperature goes negative. I get a reading from the registers of 65515, or close to (it's not exactly the same each read). Does anyone get this from the original RS485 sensors which are shipped via Tindie?

The firmware is from this project, up to date.

cheeeeee, 2021-04-17:
It's most likely going to be an integer overflow error where an unsigned value should be signed. Since it's used for watering I actually haven't bothered testing values below freezing.

chris-b-tanner, 2021-04-17:
@cheeeeee we use our sensors for controlling heaters as well as pumping water, and also to prevent pumping cycles when the water might be frozen. I suspect it's in the firmware too but my knowledge of the code isn't up to this level of debug. Is there anything in the firmware that looks suspicious to you? The fact that it's exactly at the zero crossover suggests that is is a signed/unsigned problem. There's no problem with the i2c version of this sensor which reads nicely below zero.

Miceuz, 2021-04-17:
I am not at my pc now, cant investigate, but i guess this is just receiving library thing. If you subtract 65535 you will get a correct negative number

On April 17, 2021 11:03:49 PM GMT+03:00, Chris Tanner ***@***.***> wrote:
***@***.*** we use our sensors for controlling heaters as well as pumping
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

--
Sent from my Android device with K-9 Mail. Please excuse my brevity.

cheeeeee, 2021-04-17:
It'll be lines 27-35 of main.c then most likely if the ic2 read correctly below zero where int16 is mismatched from uint16.  The array declaration probably has type conversion of the contents.

chris-b-tanner, 2021-04-18:
@cheeeeee if you have time to fix on your fork, I'm happy to run some hardware tests below zero. I believe your fork also has a fix for issue with reading interval resetting which isn't yet in this repo?

Miceuz, 2021-04-18:
Guys, I don't get what are you talking about - both in main.c and in measurement.c (where actual measurement is performed) and in thermistor code - everywhere I see signed type used.

What are you using to read the sensor? If it's python library provided by me, then update it, I have fixed this in the library more than a year ago. And I am seeing negative temperatures - I have done environmental chamber tests a year ago.

Also note that at modbus master side you have to decide (or inform your modbus driver to do so) if you will interpret the reading as unsigned or a signed number. Have a look, minimalmodbus has a separete argument to specify that:

https://github.com/Miceuz/rs485-moist-sensor/blob/6bc4947f385b5dd4cc75266e2c948ae950f28cb6/utils/lib/chirp_modbus.py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

cheeeeee, 2021-04-18:
Oh no I'm referring to main.c not the .py files

`volatile union{
            uint16_t asArray[3];
            struct {
                uint16_t moisture;
                int16_t temperature;
                uint16_t fwVersion;
            } asStruct;
        } inputRegisters;`

This would be the firmware for the attiny441. Best guess is that since you have an array that's declared as unsigned the compiler may say that all things inside the array need to be unsigned and convert them. Maybe. I've sort of abandoned working with the modbus as of now since the cabling is really to expensive to deploy at scale so I just haven't looked at these sensors as of late.

https://github.com/Miceuz/rs485-moist-sensor/blob/master/src/main.c

Miceuz, 2021-04-18:
Ok, got it. This really does nothing to the negative value. Both `-12` and `65524` have the same binary representation:
`0b1111111111110100`

As I have said, the problem is in decoding at the masters side. @chris-b-tanner can you give more details on what do you use to read sensors?

BTW `65515` is `-21` really, were you testing sensors in a freezer?

cheeeeee, 2021-04-18:
Correct it would effect the sign bit on the binary so no matter what a positive would be returned. It would just drop the sign bit assuming that it wouldn't be used.

Miceuz, 2021-04-18:
No, it wouldn't affect the sign bit as unsigned numbers use this bit to store information. You can store 0-65535 or -32767-32768 in two bytes.

chris-b-tanner, 2021-04-18:
> As I have said, the problem is in decoding at the masters side. @chris-b-tanner can you give more details on what do you use to read sensors?
> BTW `65515` is `-21` really, were you testing sensors in a freezer?

Yes, I've been testing in a freezer. I've been using a ModbusMaster package with an ESP32/Arduino IDE to read the value, and can easily subtract 65535 when appropriate. My minsuderstanding here - thank you for input! Great pieces of kit.

Miceuz, 2021-04-19:
@chris-b-tanner you don't have to do any arithmetics, you can simply cast the result to signed type:

```c
temperature = (int16_t) node.getResponseBuffer(j);
```

Closed 2021-04-18.

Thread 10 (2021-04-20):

Possible to use 1-wire?

bvduijn, 2021-04-20:
Hi Albertas,

I see you also have a version of the moisture sensor using RS-485. I was wondering if it is possible to use 1-wire, more specific. a DS2438Z+ ADC

My idea is to use the 1-wire bus to power the chirps as well. Perhaps not using the chirp function at all but do it centrally and use the moisture sensor purely as a sensor

Hope to hear your thoughts on this.

KR
Bert

Miceuz, 2021-04-23:
While this is an interesting idea, but I am not sure if if this is the right part. I would look into implementing one wire protocol directly on attiny.
DS2438Z is an ADC, but we also need a square wave to excite the sensor.

Closed 2021-04-23.

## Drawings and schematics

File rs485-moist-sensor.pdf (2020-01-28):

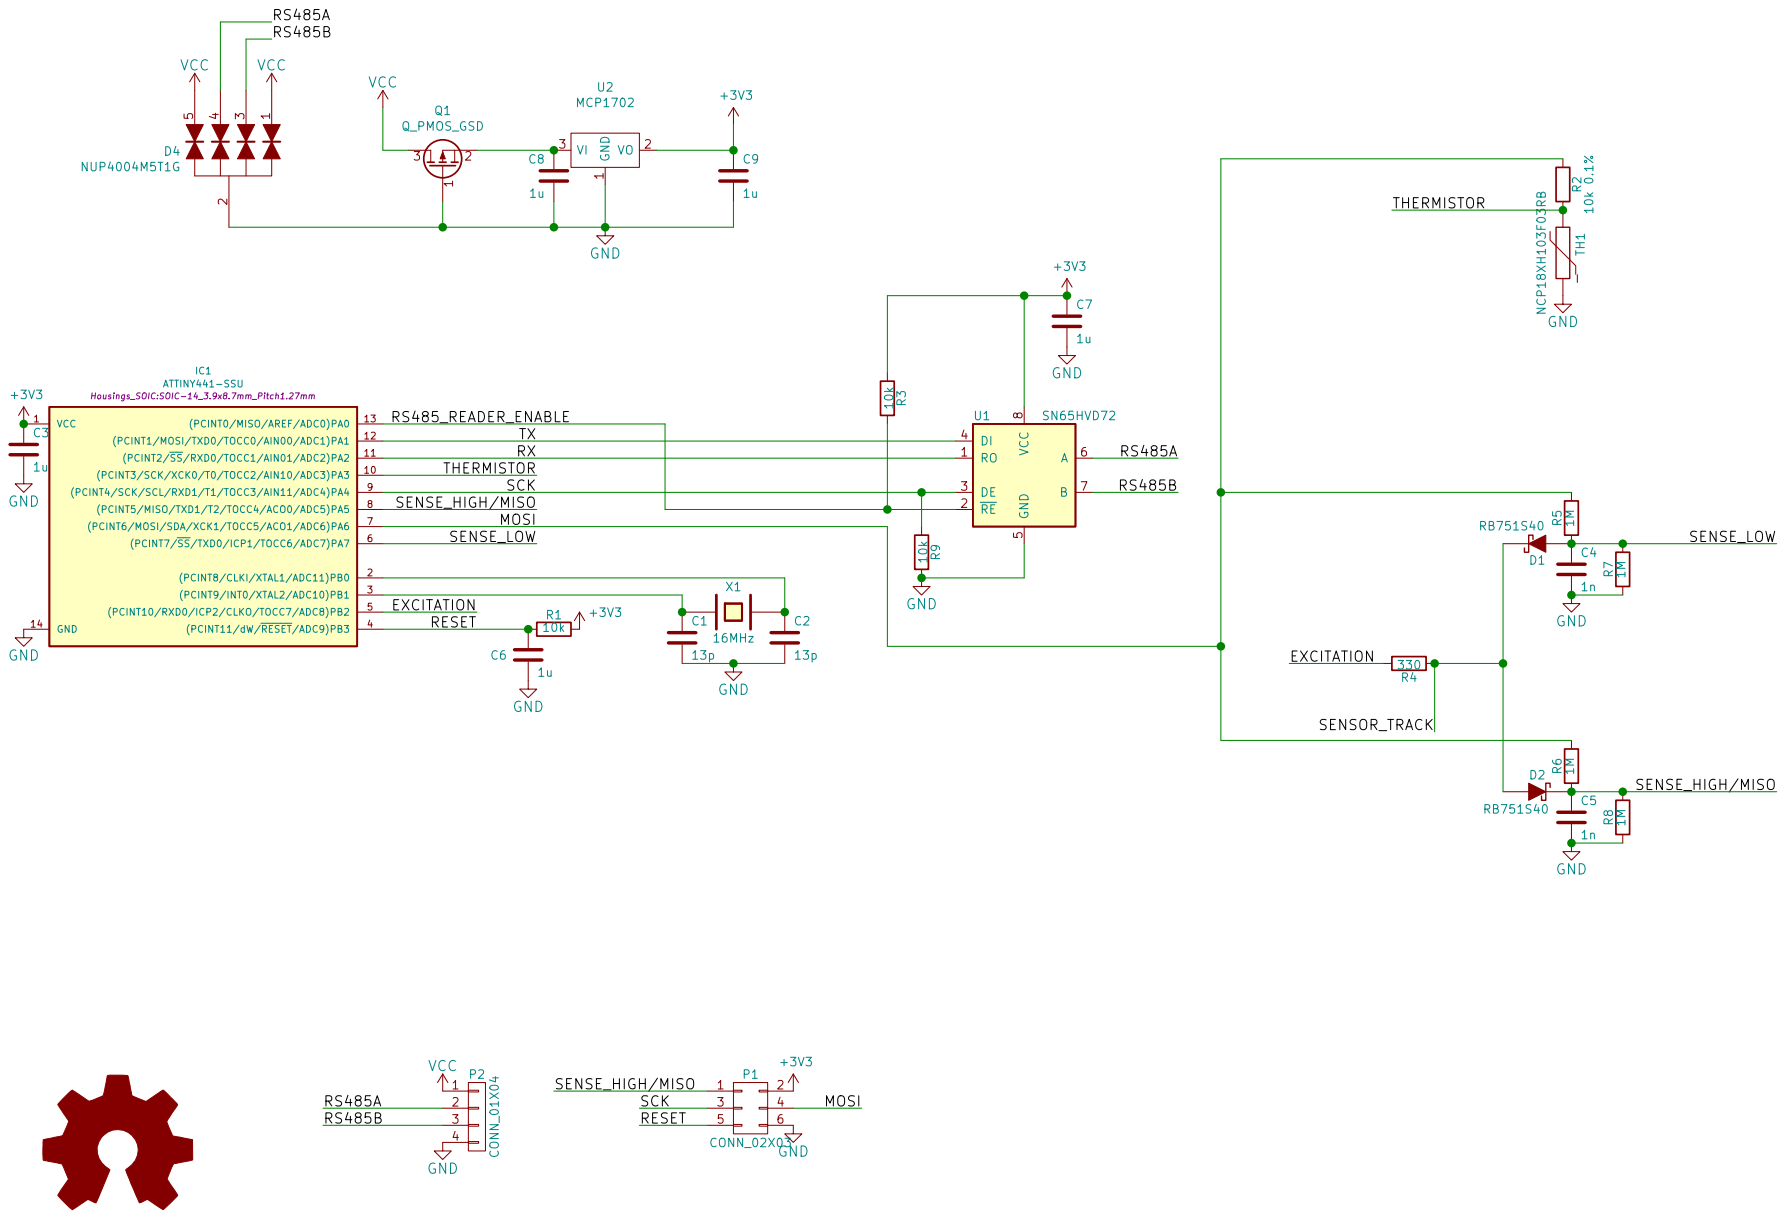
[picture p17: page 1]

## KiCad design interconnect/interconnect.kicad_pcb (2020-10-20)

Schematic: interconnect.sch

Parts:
C1: C; C_0603_1608Metric_Pad1.05x0.95mm_HandSolder
J1, J2, J3: RJ45; RJ45_Amphenol_54602-x08_Horizontal

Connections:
GND: C1.2, J1.3, J1.5, J1.7, J2.3, J2.5, J3.3, J3.5, J3.7
unnamed: J1.1, J2.1
unnamed: J1.2, J2.2
unnamed: J2.7, J3.1
unnamed: J2.8, J3.2
VCC: C1.1, J1.4, J1.6, J1.8, J2.4, J2.6, J3.4, J3.6, J3.8

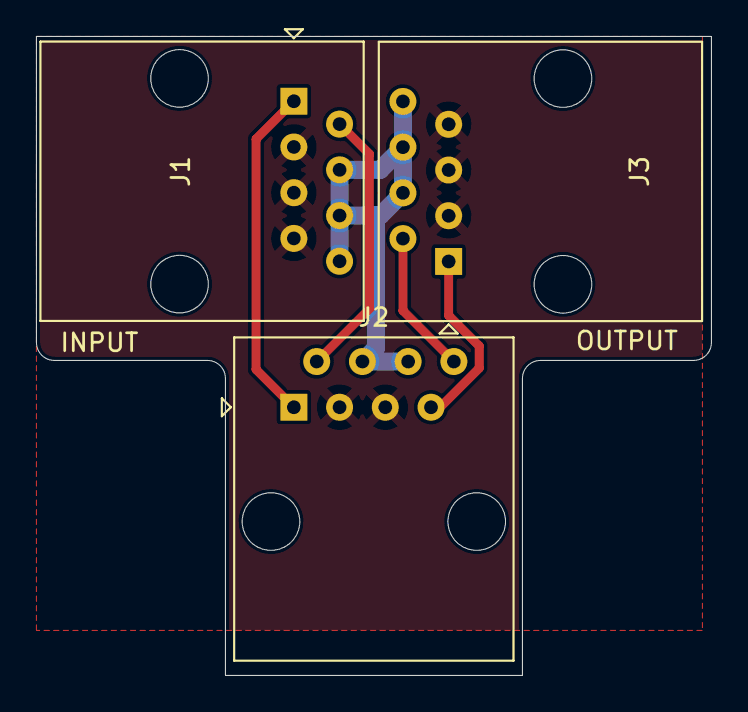
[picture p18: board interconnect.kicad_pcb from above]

Board: 2 copper layers, 37.5 x 35.5 mm, 4 parts (1 on the bottom side), 6 nets.

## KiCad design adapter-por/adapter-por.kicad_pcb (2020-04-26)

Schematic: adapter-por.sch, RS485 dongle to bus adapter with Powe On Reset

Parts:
C1, C2, C3, C4, C5: C; C_0603_1608Metric
D1: LED; LED_0603_1608Metric
J1: Conn_01x04_Male; Pin_Header_Angled_1x04_Pitch2.54mm
J2: RJ45; RJ45_Amphenol_54602-x08_Horizontal
J3: Conn_01x02_Male; TerminalBlock_RND_205-00287_Pitch5.08mm
R1, R2, R3, R4, R5, R7: R; R_0603_1608Metric
R8: 120; R_0603_1608Metric
U1: MCP100; SOT-23
U2: MCP2505; SO-8_3.9x4.9mm_P1.27mm
U3, U4: SN74LVC1G3157; SOT-23-6

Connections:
/A: J1.2, U4.1 (B2)
/A_OUT: J2.1, R8.1, U4.4 (A)
/A_SW: C1.1, R1.1, U3.6 (S), U4.6 (S)
/B: J1.3, U3.1 (B2)
/B_OUT: J2.2, R8.2, U3.4 (A)
/VOUT: J2.4, J2.6, J2.8, U2.6 (OUT), U2.8 (OUT)
GND: C1.2, C2.2, C3.2, C4.2, C5.2, J1.4, J2.3, J2.5, J2.7, J3.1, R3.2, R4.2, R5.1, U1.3 (Vss), U2.3 (GND), U3.2 (GND), U4.2 (GND)
unnamed: C2.1, R2.2, R5.2, U2.1 (CTL)
unnamed: D1.1 (K), R7.2
unnamed: R1.2, R2.1, U1.1 (~RST)
unnamed: R3.1, U3.3 (B1)
unnamed: R4.1, U4.3 (B1)
unnamed: R7.1, U2.2 (FLG)
VCC: C3.1, D1.2 (A), J3.2, U1.2 (Vdd), U2.5 (IN), U2.7 (IN)
VDD: C4.1, C5.1, J1.1, U3.5 (Vcc), U4.5 (Vcc)

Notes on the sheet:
BRW

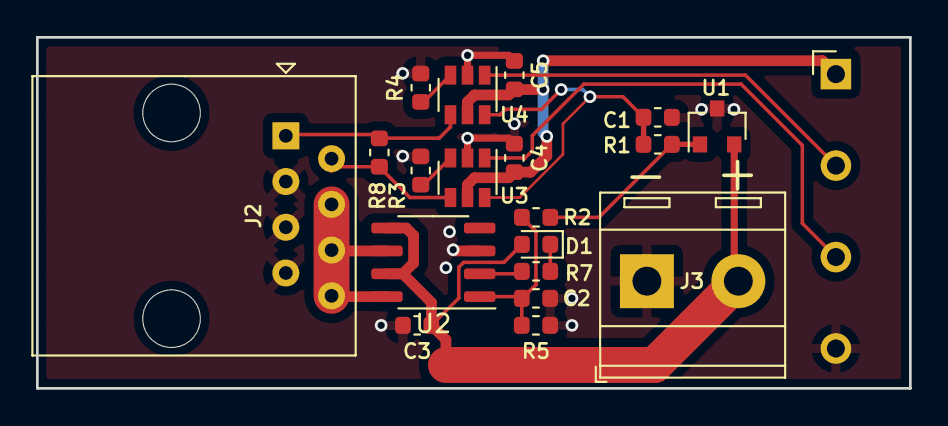
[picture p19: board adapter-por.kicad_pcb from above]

Board: 2 copper layers, 48.5 x 19.5 mm, 20 parts (0 on the bottom side), 15 nets.

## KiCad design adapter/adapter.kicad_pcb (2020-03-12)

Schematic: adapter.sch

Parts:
J1: Conn_01x04_Male; Pin_Header_Angled_1x04_Pitch2.54mm
J2: RJ45; RJ45_Amphenol_54602-x08_Horizontal
J3: Conn_01x02_Male; TerminalBlock_RND_205-00287_Pitch5.08mm
JP1, JP2: Jumper_2_Open; SolderJumper-2_P1.3mm_Open_Pad1.0x1.5mm
JP3: Jumper_3_Bridged12; SolderJumper-3_P1.3mm_Bridged12_RoundedPad1.0x1.5mm_NumberL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

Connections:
/A: J1.2, J2.1
/A/GND: J2.7, JP2.1 (A)
/B: J1.3, J2.2
/B/VCC: J2.8, JP1.1 (A)
GND: J1.4, J2.3, J2.5, J3.2, JP2.2 (B)
unnamed: J1.1, JP3.1 (A)
unnamed: J3.1, JP3.3 (B)
VCC: J2.4, J2.6, JP1.2 (B), JP3.2 (C)

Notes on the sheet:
BRW

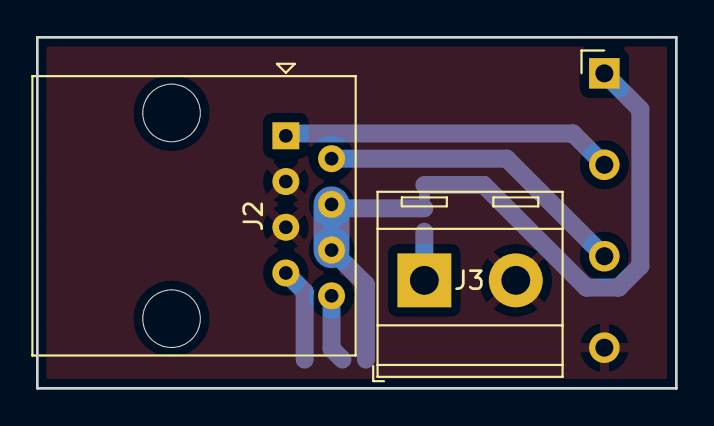
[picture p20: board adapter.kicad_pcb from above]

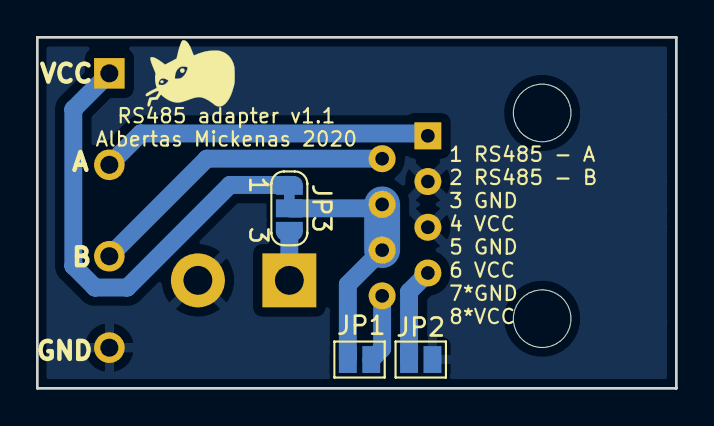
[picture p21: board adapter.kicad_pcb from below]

Board: 2 copper layers, 35.5 x 19.5 mm, 6 parts (3 on the bottom side), 8 nets.

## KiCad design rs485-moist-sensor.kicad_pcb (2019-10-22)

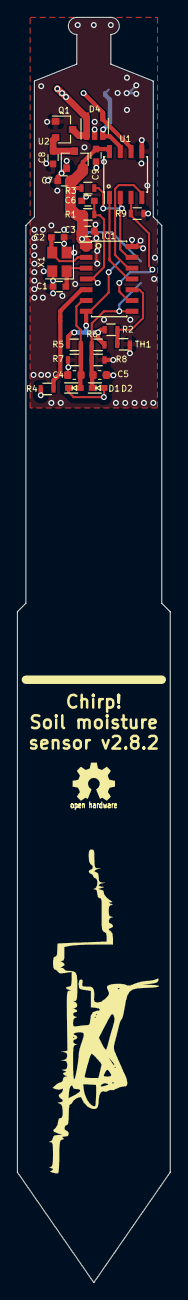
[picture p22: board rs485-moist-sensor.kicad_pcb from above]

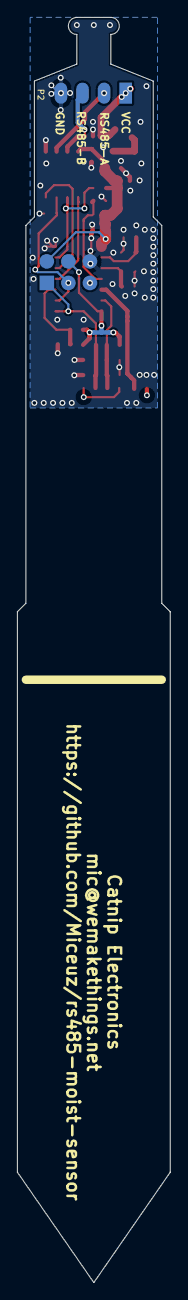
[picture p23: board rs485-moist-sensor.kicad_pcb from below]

Board: 4 copper layers, 18.0 x 149.0 mm, 29 parts (2 on the bottom side), 19 nets.

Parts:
C1, C2: 13p; C_0603
C3, C6, C7, C8, C9: 1u; C_0603
C4, C5: 1n; C_0603_1608Metric
D1, D2: RB751S40; SOD-523
D4: NUP4004M5T1G; SOT-23-5
IC1: ATTINY441-SSU; SOIC-14_3.9x8.7mm_Pitch1.27mm
P1: CONN_02X03; Pin_Header_Straight_2x03
P2: CONN_01X04; Pin_Header_Straight_1x04_Pitch2.54mm
Q1: Q_PMOS_GSD; SOT-23
R1, R3, R9: 10k; R_0603
R2: 10k 0.1%; R_0603
R4: 330; R_0603
R5, R6, R7, R8: 1M; R_0603
TH1: NCP18XH103F03RB; R_0603
U1: SN65HVD72; SOIC-8_3.9x4.9mm_Pitch1.27mm
U2: MCP1702; SOT-23
X1: 16MHz; Crystal_SMD_3225-4pin_3.2x2.5mm

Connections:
+3V3: C3.1, C7.1, C9.1, IC1.1, P1.2, R1.2, R3.1, U1.8, U2.2
/EXCITATION: IC1.5, R4.2
/MOSI: IC1.7, P1.4, R2.1, R5.2, R6.2
/RESET: C6.1, IC1.4, P1.5, R1.1
/RS485A: D4.4, P2.2, U1.6
/RS485B: D4.3, P2.3, U1.7
/RS485_READER_ENABLE: IC1.13, R3.2, U1.2
/RX: IC1.11, U1.1
/SCK: IC1.9, P1.3, R9.1, U1.3
/SENSE_HIGH/MISO: C5.1, D2.2, IC1.8, P1.1, R6.1, R8.2
/SENSE_LOW: C4.1, D1.1, IC1.6, R5.1, R7.2
/SENSOR_TRACK: D1.2, D2.1, R4.1
/THERMISTOR: IC1.10, R2.2, TH1.1
/TX: IC1.12, U1.4
GND: C1.2, C2.2, C3.2, C4.2, C5.2, C6.2, C7.2, C8.2, C9.2, D4.2, IC1.14, P1.6, P2.4, Q1.1, R7.1, R8.1, R9.2, TH1.2, U1.5, U2.1, X1.2, X1.4
unnamed: C1.1, IC1.3, X1.1
unnamed: C2.1, IC1.2, X1.3
unnamed: C8.1, Q1.2, U2.3
VCC: D4.1, D4.5, P2.1, Q1.3

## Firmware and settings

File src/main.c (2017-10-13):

/**
Version history:

0x1000 -- initial
0x1001 -- bugfix, allow address change
0x1100 -- new feature - watchdog timer always on, fix sleep times, add firmware version input register 

Versioning number structure:
0x[major version, 4bit][feature update, 4bit][bugfix 8bit]
*/
#define FIRMWARE_VERSION 0x1100

#include <stdbool.h>
#include <inttypes.h>
#include <avr/io.h>
#include <avr/interrupt.h>
#include <util/delay.h>
#include <stdio.h>
#include <avr/sleep.h>
#include "modbus.h"
#include <avr/eeprom.h>
#include <measurement.h>

#define DRIVER_ENABLE PA4
#define READER_ENABLE PA0

volatile union{
            uint16_t asArray[3];
            struct {
                uint16_t moisture;
                int16_t temperature;
                uint16_t fwVersion;
            } asStruct;
        } inputRegisters;

volatile union{
            uint16_t asArray[5];
            struct {
                uint16_t address;
                uint16_t baud;
                uint16_t parity;
                uint16_t measurementIntervalMs;
                uint16_t sleepTimeS;
            } asStruct;
        } holdingRegisters;

uint8_t eeprom_address EEMEM = 1;
uint8_t eeprom_baudIdx EEMEM = 4;
uint8_t eeprom_parityIdx EEMEM = 0;
uint16_t eeprom_measurementIntervalMs EEMEM = 500;

uint8_t temp = 0;

inline static void serialReaderDisable() {
    PORTA |= _BV(READER_ENABLE);
}

inline static void serialDriverDisable() {
    PORTA &= ~_BV(DRIVER_ENABLE);
}

inline static void serialDriverEnable() {
    serialReaderDisable();
    PORTA |= _BV(DRIVER_ENABLE);
}

inline static void serialReaderEnable() {
    serialDriverDisable();
    PORTA &= ~_BV(READER_ENABLE);
}


void transceiver_txen(void) {
    serialDriverEnable();
}

void transceiver_rxen(void) {
    serialReaderEnable();
}

inline static void reset() {
    WDTCSR = _BV(WDE);//reset in 16ms
    while(1);
} 

inline static bool isValidAddress(uint8_t address) {
    return address > 0 && address < 248;
}

inline static bool isValidBaud(uint8_t baudIdx) {
    return baudIdx >=0 && baudIdx < 8;
}

inline static bool isValidParity(uint8_t parityIdx) {
    return parityIdx >=0 && parityIdx < 3;
}

static inline bool isAddressRegisterSet() {
    return 0 == modbusGetRegisterNumber();
}

static inline bool isBaudRegisterSet() {
    return 1 == modbusGetRegisterNumber();
}

static inline bool isParityRegisterSet() {
    return 2 == modbusGetRegisterNumber();
}

static inline bool isMeasurementIntervalRegisterSet() {
    return 3 == modbusGetRegisterNumber();
}

void saveByteAndReset(uint8_t *eeprom, uint8_t value) {
    eeprom_write_byte(eeprom, value);                    
    while(!modbusIsIdle()) {
        //wait
    }
    reset();
}

void modbusGet(void) {
    if (modbusIsFrameAvailable()) {
        switch(modbusGetFunctionCode()) {
            case fcReadHoldingRegisters: {
                modbusExchangeRegisters(holdingRegisters.asArray, 5);
            }
            break;
            
            case fcReadInputRegisters: {
                modbusExchangeRegisters(inputRegisters.asArray, 3);
            }
            break;
            
//            case fcPresetMultipleRegisters:
            case fcPresetSingleRegister: {
                modbusExchangeRegisters(holdingRegisters.asArray, 5);
                if(isAddressRegisterSet()){
                    if(isValidAddress(holdingRegisters.asStruct.address)) {
                        saveByteAndReset(&eeprom_address, holdingRegisters.asStruct.address);
                    }
                } else if (isBaudRegisterSet()) {
                    if(isValidBaud(holdingRegisters.asStruct.baud)) {
                        saveByteAndReset(&eeprom_baudIdx, holdingRegisters.asStruct.baud);
                    }
                } else if (isParityRegisterSet()) {
                    if(isValidParity(holdingRegisters.asStruct.parity)) {
                        saveByteAndReset(&eeprom_parityIdx, holdingRegisters.asStruct.parity);
                    }
                } else if(isMeasurementIntervalRegisterSet()) {
                    eeprom_write_word(&eeprom_measurementIntervalMs, holdingRegisters.asStruct.measurementIntervalMs);
                }
            }
            break;
            
            default: {
                modbusSendException(ecIllegalFunction);
            }
            break;
        }
    }
}

volatile uint16_t sleepTimes = 0;
volatile uint16_t secondsToSleep = 0;

#define WDT_TIMEOUT_8S      0b00100001
#define WDT_TIMEOUT_4S      0b00100000
#define WDT_TIMEOUT_2S      0b00000111
#define WDT_TIMEOUT_1S      0b00000110
#define WDT_TIMEOUT_05S     0b00000101
#define WDT_TIMEOUT_025S    0b00000100
#define WDT_TIMEOUT_0125S   0b00000011
#define WDT_TIMEOUT_64MS    0b00000010
#define WDT_TIMEOUT_32MS    0b00000001
#define WDT_TIMEOUT_16MS    0b00000000
#define WDT_TIMEOUT_DEFAULT WDT_TIMEOUT_0125S

void wdtSetTimeout(uint8_t timeout) {
    timeout |= _BV(WDE);
    CCP = 0xD8;
    WDTCSR = timeout;
}

inline static void wdtInterruptEnable(){
    WDTCSR |= _BV(WDIE);
}

inline static void wdtInterruptDisable(){
    WDTCSR &= ~_BV(WDIE);
}

ISR(WDT_vect) {
   //Just wakeup. For some reason enabling WDT interrupt inside of ISR does not work, so we do it in sleep loop 
}

static inline void sleepSetup() {
    if(secondsToSleep >= 8) {
        wdtSetTimeout(WDT_TIMEOUT_8S);
        sleepTimes = secondsToSleep / 8;
        secondsToSleep = secondsToSleep - sleepTimes * 8;

    } else if(secondsToSleep >= 4) {
        wdtSetTimeout(WDT_TIMEOUT_4S);
        sleepTimes = 1;
        secondsToSleep = secondsToSleep - 4;
    
    } else if(secondsToSleep >= 2) {
        wdtSetTimeout(WDT_TIMEOUT_2S);
        sleepTimes = 1;
        secondsToSleep = 1;//secondsToSleep - 2;
    
    } else if(secondsToSleep == 1) {
        wdtSetTimeout(WDT_TIMEOUT_1S);
        sleepTimes = 1;
        secondsToSleep = secondsToSleep - 1;
    }
}

void sleep() {
    measurementReset();
    PORTA = 0;

    serialDriverDisable();
    serialReaderDisable();
    UCSR0B &= ~_BV(TXEN0);

    secondsToSleep = holdingRegisters.asStruct.sleepTimeS;
    holdingRegisters.asStruct.sleepTimeS = 0;

    sleepSetup();
    set_sleep_mode(SLEEP_MODE_PWR_DOWN);

    asm("WDR");
    while((sleepTimes > 0) || (secondsToSleep > 0)) {
        while(sleepTimes > 0) {
            wdtInterruptEnable();
            sleep_mode();
            sleepTimes--;
        }
        sleepSetup();
    }

    wdtInterruptDisable();
    wdtSetTimeout(WDT_TIMEOUT_DEFAULT);

    performMeasurement((uint16_t*) &(inputRegisters.asStruct.moisture), 
                            (uint16_t*) &(inputRegisters.asStruct.temperature));

    UCSR0B |= _BV(TXEN0);
    serialReaderEnable();
}

inline static bool isSleepTimeSet() {
    return 0 != holdingRegisters.asStruct.sleepTimeS;
}

inline static void saveConfig() {
    eeprom_write_byte(&eeprom_address, holdingRegisters.asStruct.address);
    eeprom_write_byte(&eeprom_baudIdx, holdingRegisters.asStruct.baud);
    eeprom_write_byte(&eeprom_parityIdx, holdingRegisters.asStruct.parity);
    eeprom_write_word(&eeprom_measurementIntervalMs, holdingRegisters.asStruct.measurementIntervalMs);
}

inline static void loadConfig() {
    inputRegisters.asStruct.fwVersion = FIRMWARE_VERSION;
    holdingRegisters.asStruct.sleepTimeS = 0;

    temp = eeprom_read_byte(&eeprom_address);
    
    if(isValidAddress(temp)) {
        holdingRegisters.asStruct.address = temp;
    } else {
        holdingRegisters.asStruct.address = 1;
    }

    temp = eeprom_read_byte(&eeprom_baudIdx);
    if(temp >= 0 && temp < 8) {
        holdingRegisters.asStruct.baud = temp;
    } else {
        holdingRegisters.asStruct.baud = 4;
    }

    temp = eeprom_read_byte(&eeprom_parityIdx);
    if(temp >=0 && temp < 3) {
        holdingRegisters.asStruct.parity = temp;
    } else {
        holdingRegisters.asStruct.parity = 0;
    }

    holdingRegisters.asStruct.measurementIntervalMs = eeprom_read_word(&eeprom_measurementIntervalMs);
    if(65535 == holdingRegisters.asStruct.measurementIntervalMs) {
        holdingRegisters.asStruct.measurementIntervalMs = 500;
    }
}

void main (void) {
    wdtSetTimeout(WDT_TIMEOUT_DEFAULT);

    DDRA |= _BV(DRIVER_ENABLE);
    DDRA |= _BV(READER_ENABLE);

    // DDRA |= _BV(PA3);
    // PINA |= _BV(PA3);
    // _delay_ms(100);
    // PINA |= _BV(PA3);

    loadConfig();

    modbusSetAddress(holdingRegisters.asStruct.address);
    modbusInit(holdingRegisters.asStruct.baud, holdingRegisters.asStruct.parity);

    adcSetup();    
    sei();    
    timer1msStart(&(holdingRegisters.asStruct.measurementIntervalMs));

    performMeasurement((uint16_t*) &(inputRegisters.asStruct.moisture), 
                            (uint16_t*) &(inputRegisters.asStruct.temperature));

    serialReaderEnable();

    while(1) {
        processMeasurements((uint16_t*) &(inputRegisters.asStruct.moisture), 
                            (uint16_t*) &(inputRegisters.asStruct.temperature));
        modbusGet();

        if(isSleepTimeSet() && modbusIsIdle() && modbusIsTXComplete()) {
            sleep();
        }
        asm("WDR");
    }
}

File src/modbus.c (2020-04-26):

/************************************************************************
Title:    Yet another (small) Modbus (server) implementation for the avr.
Author:   Max Brueggemann, Albertas Mickenas
Hardware: AVR ATtiny441 at 16MHz
License:  GNU General Public License

LICENSE:
    Copyright (C) 2017 Max Brueggemann, Albertas Mickenas

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
************************************************************************/

#include <avr/io.h>
#include <stdbool.h>
#include <avr/interrupt.h>
#include "modbus.h"

#define UART_TRANSMIT_COMPLETE_INTERRUPT USART0_TX_vect
#define UART_RECEIVE_INTERRUPT   USART0_RX_vect
#define UART_TRANSMIT_INTERRUPT  USART0_UDRE_vect
#define UART_STATUS   UCSR0A
#define UART_CONTROL  UCSR0B
#define UART_DATA     UDR0
#define UART_UDRIE    UDRIE0
#define UCSRC UCSR0C
#define RXCIE RXCIE0
#define TXCIE TXCIE0
#define RXEN RXEN0
#define TXEN TXEN0
#define UCSZ0 UCSZ00
#define U2X U2X0
#define UBRRH UBRR0H
#define UBRRL UBRR0L

#define ADDRESS_BROADCAST 0

typedef enum{
	STATE_INITIAL,
	STATE_IDLE,
	STATE_RECEPTION,
	STATE_CONTROL,
	STATE_EMISSION
} BusState_t;

#define maxFrameIndex 31
volatile uint8_t sendPacketTopIndex = 0;
volatile uint8_t rxbuffer[32];
uint16_t timeout15 = 0;
uint16_t timeout35 = 0;
volatile BusState_t busState;
volatile bool frameNOK = false;
volatile bool frameAvailable = false;
uint8_t ownAddress = 0;
volatile uint8_t dataPos = 0;


/* @brief: A fairly simple Modbus compliant 16 Bit CRC algorithm.
*
*  	Returns 1 if the crc check is positive, returns 0 and saves the calculated CRC bytes
*	at the end of the data array if it fails.
*  	
*/
uint8_t crc16(volatile uint8_t *ptrToArray,uint8_t inputSize) //A standard CRC algorithm
{
	uint16_t out=0xffff;
	uint16_t carry;
	unsigned char n;
	inputSize++;
	for (int l=0; l<inputSize; l++) {
		out ^= ptrToArray[l];
		for (n = 0; n < 8; n++) {
			carry = out & 1;
			out >>= 1;
			if (carry) out ^= 0xA001;
		}
	}
	//out=0x1234;
	if ((ptrToArray[inputSize]==out%256) && (ptrToArray[inputSize+1]==out/256)) //check
	{
		return 1;
	} else { 
		ptrToArray[inputSize]=out%256; //append Lo
		ptrToArray[inputSize+1]=out/256; //append Hi
		return 0;	
	}
}

void start35Timer() {
    TCNT2 = 0;
    OCR2B = timeout35;
    TIMSK2 |= _BV(OCIE2B);
    TIFR2 |= _BV(OCF2B);
    TCCR2B = _BV(CS21);
}

void start15Timer() {
    TCNT2 = 0;
    OCR2A = timeout15;
    TIMSK2 |= _BV(OCIE2A);
    TIFR2 |= _BV(OCF2A);
    TCCR2B = _BV(CS21);
}

static inline void stop15Timer() {
    TIMSK2 &= ~_BV(OCIE2A);
}

static inline bool isTimer15Off() {
	return 0 == (TIMSK2 & _BV(OCIE2A));
}

static inline void stop35Timer() {
    TIMSK2 &= ~_BV(OCIE2B);
    if(isTimer15Off()) {
    	TCCR2B = 0;
    }
}

inline static void initFrame() {
	dataPos = 0;
	frameNOK = false;
	frameAvailable = false;
}

void modbusSetAddress(uint8_t address) {
	ownAddress = address;
}

inline static bool isFrameAddressedToUs() {
	return ownAddress == rxbuffer[0] || ADDRESS_BROADCAST == rxbuffer[0];
}

inline static bool isFunction(const uint8_t fCode) {
	return rxbuffer[1] == fCode;
}

/* @brief:  Returns the amount of requested data objects (coils, discretes, registers)
*
*/
inline static uint8_t getRequestedRegisterCount(void) {
	if (rxbuffer[1]==fcPresetSingleRegister) {
		return 1;
	} else {
		return (uint8_t)(rxbuffer[5]|(rxbuffer[4]<<8));
	}
}

/* @brief: Returns the address of the first requested data object (coils, discretes, registers)
*
*/
inline static uint8_t getRequestedAddress(void) {
	return (uint8_t)(rxbuffer[3]|(rxbuffer[2]<<8));
}

bool isBroadcastFrame() {
	return ADDRESS_BROADCAST == rxbuffer[0];
}

bool validateFrame() {
	uint8_t requestedAmount = getRequestedRegisterCount();
	uint8_t requestedAdr = getRequestedAddress();
	if (isFunction(fcReadHoldingRegisters) || isFunction(fcReadInputRegisters)) {
		if(isBroadcastFrame()){
			return false;
		}
		//requested amount of bytes must fit into buffer together with address, function code, and 2 bytes of crc 
		if((requestedAmount * 2) > (maxFrameIndex - 4)) { 
			modbusSendException(ecIllegalDataAddress);
			return false;
		}
		return true;
	} else if (isFunction(fcPresetMultipleRegisters)) {
		if (rxbuffer[6] < requestedAmount * 2) {//enough data declared in the frame?
			modbusSendException(ecIllegalDataValue);
			return false;
		}
		if ((dataPos - 9) < rxbuffer[6]) {//enough data received?
			modbusSendException(ecIllegalDataValue);
			return false;
		}
		return true;
	} else if (isFunction(fcPresetSingleRegister)) {
		if((dataPos - 6) < 2) {//enough data received? should be exactly 2 bytes, but we allow more, will use just the first two
			modbusSendException(ecIllegalDataValue);
			return false;
		} 
		return true;
	} else {
		modbusSendException(ecIllegalFunction);
		return false;
	}
}

/**
 * @brief	Character reception interrupt. Code in this interrupt handling routine plus two 
 * 			subsequent timer interrupt routines implement a RTU transmission mode state 
 * 			diagram as per "MODBUS over serial line specification and implementation 
 * 			guide V1.02" found at www.modbus.org
 */

ISR(UART_RECEIVE_INTERRUPT) {
	uint8_t parityError = (UCSR0C & _BV(UPM01) && (UCSR0A & _BV(UPE0)));
	uint8_t data = UART_DATA;
	
	switch(busState){
		case STATE_INITIAL:
			start35Timer();
			break;
		case STATE_IDLE:
			busState = STATE_RECEPTION;
			initFrame();
			rxbuffer[dataPos] = data;
			dataPos++;
			start35Timer();
			start15Timer();
			break;
		case STATE_RECEPTION:
			if(dataPos <= maxFrameIndex) {
				rxbuffer[dataPos] = data;
				dataPos++;
			} else {
				frameNOK = true;
			}
			start35Timer();
			start15Timer();
			break;
		case STATE_CONTROL:
			start35Timer();
			frameNOK = true;
			break;
		case STATE_EMISSION:
			start35Timer();
			frameNOK = true;			
	}

	// if(parityError) {
	// 	frameNOK = true;
	// }
}

/**
 * @brief	1.5 char timer interrupt
 */
ISR(TIMER2_COMPA_vect) {
	stop15Timer();
	if(STATE_RECEPTION == busState) {
		busState = STATE_CONTROL;
	}
}

/**
 * @brief	3.5 char timer interrupt
 */
ISR(TIMER2_COMPB_vect) {
	stop35Timer();
	if(STATE_INITIAL == busState) {
		busState = STATE_IDLE;
	} else if (STATE_CONTROL == busState) {
		busState = STATE_IDLE;
		if(!frameNOK && isFrameAddressedToUs() && crc16(rxbuffer, dataPos - 3)) {
			if(validateFrame()) {
				frameAvailable = true;
			}
		}
	} else if (STATE_EMISSION == busState) {
		busState = STATE_IDLE;
	}
}

volatile uint8_t txComplete = 0;

/* @brief: Sends a response.
*
*         Arguments: - packtop: Position of the last byte containing data.
*                               modbusSendException is a good usage example.
*/
void modbusSendMessage(unsigned char packtop) {
	if(isBroadcastFrame()) {
		return;
	}

	sendPacketTopIndex = packtop+2;
	crc16(rxbuffer,packtop);
	dataPos = 0;

	transceiver_txen();
	busState = STATE_EMISSION;
	frameAvailable = false;
	UART_CONTROL|=(1<<UART_UDRIE);
	txComplete = 0;
}
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

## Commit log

2015-02-16 Add schematics PDF
    [rs485-moist-sensor.sch]
2015-04-25 Move trace so that it does not touch a square MOSI pad
    [rs485-moist-sensor.kicad_pcb]
2015-04-25 Some most recent changes
    [rs485-moist-sensor.sch]
2015-04-25 Add gerbers
    [rs485-moist-sensor-B_Cu.gbr, rs485-moist-sensor-B_Mask.gbr, rs485-moist-sensor-B_SilkS.gbr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]
2015-04-25 Add thermistor datasheet
2015-04-25 Some basic code - thermistor and capacitance readings work, rs485 works
2015-04-26 Fiddle around with RS485 transceiver lib symbol -- pins were dangerously swapped!
    [rs485-moist-sensor.kicad_pcb]
2015-04-26 Move thermistor code to the separate module
2017-02-03 Specify thermistor
    [rs485-moist-sensor.sch]
2017-02-05 Add a local voltage regulator, add antistatic protection, specify transceiver, change attiny441 package to soic-14, route everything
    [rs485-moist-sensor.kicad_pcb, rs485-moist-sensor.sch]
2017-02-05 Remove outdated and generated stuff
    [bom.csv]
2017-04-18 Added BOM from kicad generator
2017-04-18 Another board spin - add 3.3v regulator, other rs485 transceiver, esd protection
    [User Library-CAP_SMD-1.STEP, User Library-Crystal HC49_US-SM.STEP, User Library-LTST-C190GKT.STEP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]
2017-04-18 Add part numbers and Farnell order numbers to the mail components
    [rs485-moist-sensor.sch]
2017-04-24 Add a via so that programming header ground is connected
    [rs485-moist-sensor.kicad_pcb]
2017-04-24 There is no more led, pin assignments have changed
2017-04-25 Emable extended fuse programming in the Makefile, se BOD to enabled in active mode, to switched in power down mode
2017-04-25 Re-route TVS connection, hook up ground of the programming header
    [rs485-moist-sensor.kicad_pcb]
2017-04-25 Add a pulldown resistor to make transceiver more robust
    [rs485-moist-sensor.sch]
2017-04-25 Pullup/pulldown resistors to put rs485 transceiver in off mode by default. Connect DE, ~RE lines to MCU separately. Provide power to resistive dividers from MCU, not from regulator to allow for lower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
    [rs485-moist-sensor.kicad_pcb, rs485-moist-sensor.sch]
2017-04-25 Add manufacturing files
    [bom.xls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]
2017-04-25 Put values into place
    [rs485-moist-sensor.kicad_pcb]
2017-05-03 Fix the back silkscreen
    [rs485-moist-sensor-pannel-B.Cu.gbr, rs485-moist-sensor-pannel-B.Mask.gbr, rs485-moist-sensor-pannel-B.SilkS.gbr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]
2017-05-23 Smaller buffer! Some code reformatting. Some refactoring. A couple of new helper functions
2017-05-23 A bunch of changes comming with modbus integration: * RS485 direction control by using two separate receiver and transmitter control lines * Provide moisture in input register * Provide temperature i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
    [main.c]
2017-05-25 Clear timer otput capture flags as they are appearently set even without interrupts enabled
2017-05-25 Loose the fight for parity - the most of cheap usb to serial dongles don't support even/odd parity properly, so drop the requirement to be even parity by default, and configure to use no parity by de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
    [main.c, modbus.c, test.py]
2017-06-19 Fix a missing ground connection. Make PCB updatable from schematics directly
    [rs485-moist-sensor.kicad_pcb, rs485-moist-sensor.sch]
2017-06-19 Add a step file of the sensor
    [rs485-moist-sensor.stp]
2017-06-19 Add protective measures so that bogus data can not be loaded form eeprom even though it should never be able to get there. Make measurements after reset and after sleep to avoid potential long wait f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
    [main.c, measurement.c]
2017-06-28 Initialize the settings to defaults more vigoriously, including measurement interval. Enable reader, not driver
2017-09-12 Fix a shameful error of not have being tested full functionality after the huge refactoring
    [main.c, modbus.c]
2017-10-12 A STEP file
    [rs485-moist-sensor.stp]
2017-10-13 Enable the watchdog in fuses, set it up to 2s timeout. Just for testing now
2017-10-13 Disable WDT in fuses as this does not allow us to use WDT interrupt. Add a method to check if all the communicaiton is done before going to sleep. Fix sleep functionality so that the sensor sleeps ex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
    [main.c, modbus.c, modbus.h]
2018-09-03 Changed crystal to SMD 3225
    [CRY_SMD3225.STEP, rs485-moist-sensor.kicad_pcb]
2018-09-04 added 3d model for crystal SMD 3225
    [rs485-moist-sensor.kicad_pcb]
2018-09-04 4 layer configuration
    [rs485-moist-sensor.kicad_pcb]
2018-09-05 GND into inner layers
    [rs485-moist-sensor.kicad_pcb]
2018-09-05 gerbers and drill files
    [rs485-moist-sensor-B.Cu.gbr, rs485-moist-sensor-B.Mask.gbr, rs485-moist-sensor-B.SilkS.gbr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]
2018-09-11 New kicad library order
    [rs485-moist-sensor-B.Cu.gbr, rs485-moist-sensor-B.Mask.gbr, rs485-moist-sensor-B.SilkS.gbr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]
2018-09-11 Add measurement data
    [initial-value-distribution-cleanup.csv, initial-value-distribution.csv, initial-value-distribution2.csv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]
2018-09-11 Fill zones
    [rs485-moist-sensor.kicad_pcb]
2019-08-27 Fix busScan documentation in tutorial, add another example of sensor data being pushed to InfluxDB
2019-10-08 Add crystal model
    [CRY_SMD3225.STEP]
2019-10-22 Update the sensor outline to accomodate narrower heatshrink. Also change ziptie application feature
    [rs485-moist-sensor.kicad_pcb, rs485-moist-sensor.sch]
2019-10-22 Ignore schematics backups
2019-10-22 Update capacitance to accomodate crystal change. Tidyup fabrication layers
    [rs485-moist-sensor.kicad_pcb, rs485-moist-sensor.sch]
2020-01-24 Add sensor RJ45 interconnect board
    [interconnect-B_Cu.gbr, interconnect-B_Mask.gbr, interconnect-B_SilkS.gbr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]
2020-01-24 Remove gerbers as they are generated
    [interconnect-B_Cu.gbr, interconnect-B_Mask.gbr, interconnect-B_SilkS.gbr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]
2020-01-28 Add RJ45 adapter board to RS485 dongle
    [adapter-B_Cu.gbr, adapter-B_Mask.gbr, adapter-B_SilkS.gbr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]
2020-01-28 Export schematics PDF that looks a bit better
2020-02-10 Relabel nets
    [interconnect.sch]
2020-03-12 Add some adapter and interconnect pics
    [adapter.kicad_pcb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]
2020-03-12 Kicad version shifting junk
    [rs485-moist-sensor-2018-02-15-12-32-34.sch, rs485-moist-sensor-2019-10-08-23-19-40.sch]
2020-03-12 Fix up the test utility
    [test.py]
2020-03-18 Release a new library version to properly use the current version of minimalmodbus
2020-03-22 Chase KiCad file updates
2020-04-03 Add cable marker link
    [adapter.sch]
2020-04-03 Add adapter with Power On Reset circuit to maybe mitigate eeprom corruption problem in current FW batch
    [adapter-por-B_Cu.gbr, adapter-por-B_Mask.gbr, adapter-por-B_SilkS.gbr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]
2020-04-26 POR adapter fixups
    [adapter-por.kicad_pcb]
2020-04-26 Fix a variable with no type
    [modbus.c]
2020-10-20 Add step models for rj45 connectors
    [54602-908LFc.stp, interconnect.kicad_pcb]
2021-03-11 Add Arduino example that communicated to the sensor
2023-10-16 Change defaut port number, update to python 3 prints
2023-12-04 Add cable pinout to sensor schematics
    [rs485-moist-sensor.kicad_sch]
